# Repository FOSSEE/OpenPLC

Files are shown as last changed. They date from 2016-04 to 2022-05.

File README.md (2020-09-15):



# Introduction

- [Introduction](#introduction)
  - [What is OpenPLC?](#what-is-openplc)
  - [Our story](#our-story)
  - [Our solutions](#our-solutions)
    - [Hardware](#hardware)
    - [Software](#software)
- [Community and contributing](#community-and-contributing)
  - [Forking and cloning](#forking-and-cloning)
- [Directory Structure](#directory-structure)
- [Licence](#licence)

## What is OpenPLC?

OpenPLC is an open source **P**rogrammable **L**ogic **C**ontroller(**PLC**). Our hardware/s are functionally PLCs that can be programmed using [Ladder Logic diagram (LD)](https://en.wikipedia.org/wiki/Ladder_logic), as well as [Function Block diagram (FBD)](https://en.wikipedia.org/wiki/Function_block_diagram). We have designed the systems for academic purpose and to enable effective learning of programming PLCs. For this reason, we are also providing a set of *modules* that supplement the PLCs, which can be used to perform experiments like *simple traffic light, elevator, conveyor belt etc.*

## Our story

Few years ago we came across the need for an affordable and functional PLC for educational purposes. Every year, a large number of students in our colleges are undergoing training in PLCs without proper hands-on experience. The sky-high cost of the setup is a reason, also is the high maintenance because of being used by students. Vendor specific tools and work-flow, which are often complex, is another hindrance.

## Our solutions

### Hardware

OpenPLC consists of **two** versions
- OpenPLC Version 1 : Hardware based on AVR's [**ATmega16A**](https://www.microchip.com/wwwproducts/en/ATmega16A) and programmed using **LD**
- OpenPLC Version 2 : Hardware based on [**Raspberry Pi**](https://www.raspberrypi.org/products/raspberry-pi-zero-w/) and programmed using **FBD**

As mentioned earlier, we are also providing a set of plug-and-play modules for practising a range of experiments. The current ones are
- Elevator/Conveyor belt : Consists of a timing bet, a motor and a motor driver that can be controlled.
- Temperature Sensing and control.
- Switches : an array of *normally-open, normally-closed and latch* switches.
- Simple traffic light.

### Software

The two versions of PLCs uses two different software for programming.

- [LDMicro](Software/OpenPLCV1_LDMicro/) : A simple and intuitive LD programming IDE, used for programming *OpenPLC Version 1*. It is a forked and locally maintained version of [Jonathan Westhues](https://github.com/LDmicro/LDmicro) software.
- [4diac](https://www.eclipse.org/4diac/index.php) : A system, used for *OpenPLC version 2*, that consists of an IDE and a runtime environment for FBD programming and deployment. At present we directly use the [Eclipse 4diac](https://www.eclipse.org/4diac/) project with the Raspberry Pi work-flow.
 
*Note : Detailed documentation regarding each of the above are present in the respective directories.*

___

# Community and contributing

OpenPLC is developed by [FOSSEE](https://fossee.in/) and by users like you. We welcome both pull requests and issues on GitHub. How to and guides pertaining to both *software* and *hardware* can be found in the respective directories.

## Forking and cloning

The repository consists of a few [git submodules](https://git-scm.com/book/en/v2/Git-Tools-Submodules). To clone them along with this repo use the following command.

`git clone --recurse-submodules -j8 https://github.com/FOSSEE/OpenPLC.git'

___

# Directory Structure
      .
      ├── OpenPLC_modules     # OpenPLC modules resources including designs
      ├── OpenPLC_version_1   # OpenPLC version 1 resources including designs
      ├── OpenPLC_version_2   # OpenPLC version 2 resources including designs
      ├── LICENSE             # license
      └── README.md           # this readme

<!-- A Programmable Logic Controller generally has a set of input and output ports to which the external peripherals are connected, which are
to be electrically controlled by the PLC.
Looking into the flow of working with the PLC, the processor tries to make decisions in accordance with the program, generally written by the user using some programming language is used to write the logic and program these units.
Some of the languages commonly used are Function Block Diagram, Ladder Diagram, Structured Text, Sequential Function Chart and Instruction List.

The objective is to create an Open Source PLC, which has the capabilities of an industrial PLC, but at a much affordable and simpler user interface. Currently we have 2 versions

1. Version 1 - It incorporates a development board, that works on AVR’s ATmega16A IC, giving up to 40 pins, most of which can be used and programmed as the Input-Output pins as it’s done on a PLC.
Here the Programming language used here is Ladder Logic which is one of the easiest and also, robust in terms of its efficiency.
The main point here is, this device is a standalone device, which can work without the host system being there, just being powered by a source.
HEX files to be generated according to the controller are generated by a software called __LDMicro__, freely available for Windows and Linux users alike.
The programming on the board is done via an *USB-ASP* device through ISP headers.
All the processor wants now is a code to be dumped on it to start automating your small needs.

2. Version 2 - It uses Function Block(FB) programming language to write the logic. The system is build around a Raspberry Pi Zero, which runs a realtime environment build for IEC61499 standard. The platform we are using is **4diac**, which is implementation of IEC 16499. It has got 2 components :
   * 4diac IDE - the programming interface for writing logics using FBs.
   * FORTE - the runtime present in the actual hardware-- here a Raspberry Pi.

### The Modules

We have developed 4 different modules that goes along with the PLCs for performing experiments; trying various control methods.
   * Motor module - for controlling a motor
   * Temperature Sensing and control
   * Switches - array of various types of switches
   * Traffic light. -->

The OpenPLC setup is shown below:

<!-- ![OpenPLC Version 1(early prototype)](/Images/openplc.png "OpenPLC Version 1") -->

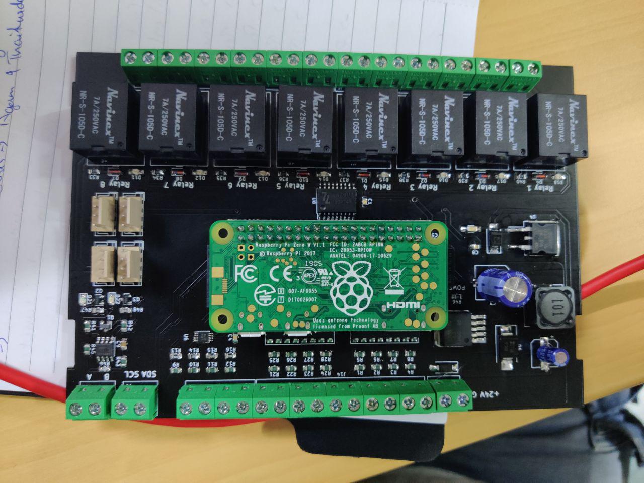
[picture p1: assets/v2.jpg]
OpenPLC Version 2


___

# Licence

OpenPLC is released under the MIT license. Some part of the software are released under other licences specified.

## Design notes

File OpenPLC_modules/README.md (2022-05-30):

# OpenPLC Modules

Addon modules for OpenPLC experiments.
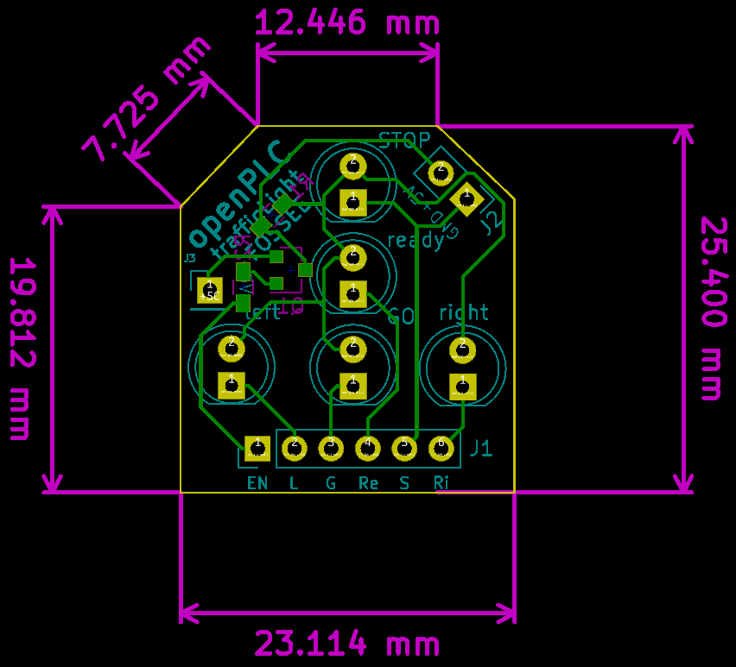
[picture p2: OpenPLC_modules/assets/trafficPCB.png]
traffic
- Traffic light - represent a 3 way traffic light 
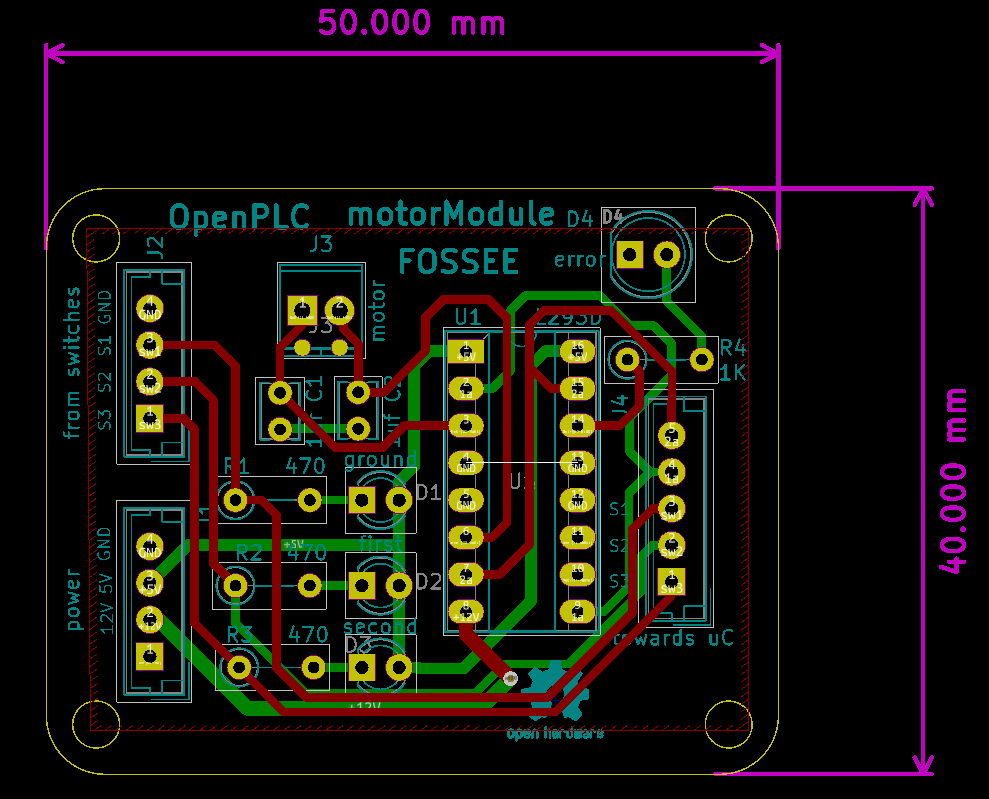
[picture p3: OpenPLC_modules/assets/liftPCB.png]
lift
- Motor driver for lift - circuit required for driving the motor, receiving and passing on the limit-switch state and as an indicator showing the given logic 
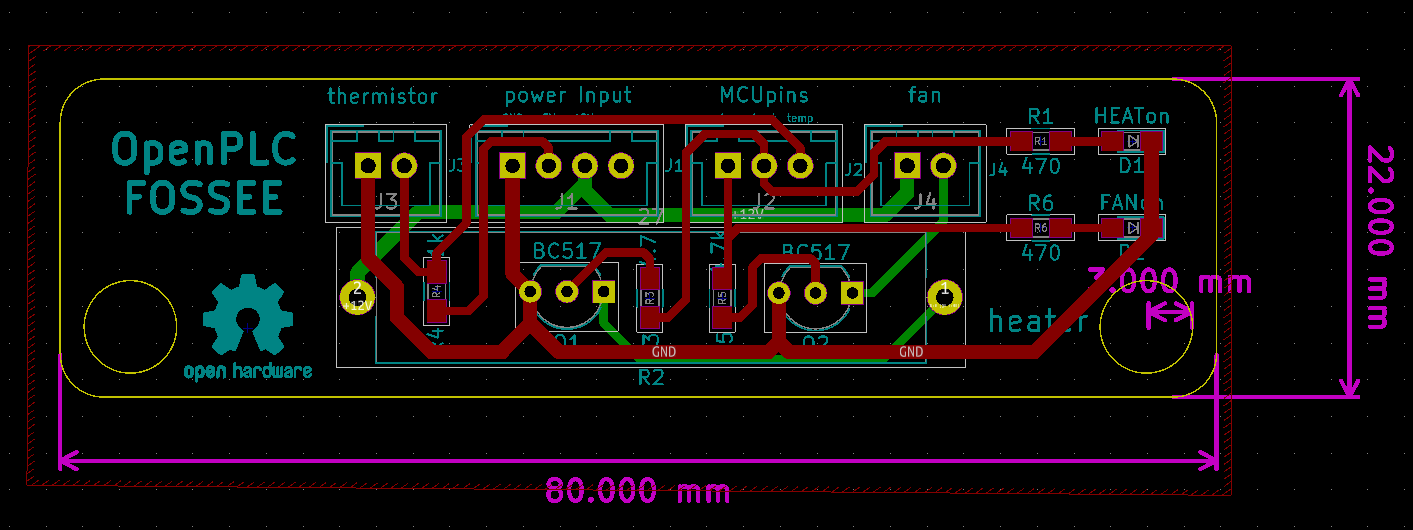
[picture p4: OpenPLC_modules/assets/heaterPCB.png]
heater
- Heater/temperature control - elements to drive the roister, which also doubles as the heating element, the cooling fan and collecting and passing on thermistor values 
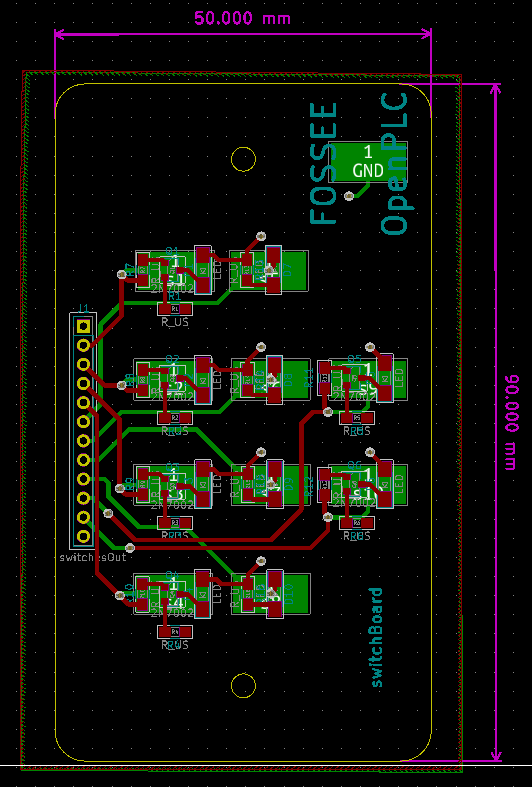
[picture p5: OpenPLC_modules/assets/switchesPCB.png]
switches
- Switches - an array of a combination of NO, NC and latch switches with indicator LEDs

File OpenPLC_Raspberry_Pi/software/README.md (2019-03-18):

# OpenPLC Version 2

Version 2 hardware is built around a Raspberry Pi. [4diac](https://www.eclipse.org/4diac/) is the associated software and you may download it from here - [Link](https://www.eclipse.org/4diac/en_dow.php).

Unlike *Version 1*, 4daic follows the [IEC 61499](https://en.wikipedia.org/wiki/IEC_61499) standard whereas the former follows **ladder logic** as defined in [IEC 6113-3](https://en.wikipedia.org/wiki/IEC_61131-3). Programs in *4daic* are written using **Function Blocks**, which are event driven sub-programs with robust data encapsulation.

## 4diac

**4daic** has got two primary components

- **4diac IDE** - It is an integrated development environment written in Java, based on the Eclipse framework. It provides an extensible engineering environment for modeling distributed control applications compliant to the IEC 61499 standard. You use 4diac IDE to create FBs, applications, configure the devices and other tasks related to IEC 61499. Within 4diac IDE, these results can also be deployed to devices running 4diac FORTE or other compliant run-time environments.

- **FORTE** - It is a small portable C++ implementation of an IEC 61499 runtime environment which supports executing IEC 61499 FB networks on small embedded devices. 4diac FORTE typically runs on top of a (real-time) OS. 4diac FORTE is a multi-threaded and low memory-consuming runtime environment. It has been tested on several different operating systems, for example, Windows, Linux (i386, amd64, ppc, xScale, arm), NetOS, eCos, rcX from Hilscher, vxWorks, and freeRTOS.

*Note: We are working on developing an exclusive forte version for our hardware and it is a work in progress. Till updated here, please choose the hardware as Raspberry Pi.*

### Learning 4diac

The official [documentation](https://www.eclipse.org/4diac/en_help.php) is the best source for learning the software a-z. You can join the [forum](https://www.eclipse.org/forums/index.php?t=thread&frm_id=308) and get support from the community too. Also, you can contact us in [***contact-openplc[at]fosse[dot]in***]().

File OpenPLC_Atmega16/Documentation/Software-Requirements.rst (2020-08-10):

Software Requirements
=====================

Many software support PLC simulation in various logic.
The software that has been used in the subsequent sections is
LDMicro, that incorporates Ladder Logic, supporting
many microcontrollers, along with the AVR's ATmega16A. This
software helps produce the HEX files according to the microcontroller
and the pin selected which can be directly dumped onto the
core.

For windows based system
------------------------

The IC is a standalone one without the Bootloader. One of the ways of
dumping the code, is using an In System Programmer or an ISP. So, for burning the same we use the software: AVRDUDE1 - AVR Downloader Uploader is a program for downloading and uploading the on-chip memories of Atmels AVR microcontrollers. It can program the Flash and EEPROM, and where supported by the serial programming protocol, it can program fuse and lock bits. It’s available as WINAVR for Windows and can be downloaded from 'here <https://sourceforge.net/projects/winavr/files/WinAVR/20100110>'_.

Setting up WINAVR
~~~~~~~~~~~~~~~~~

Step 1: First, open up the start screen and then search : Command Prompt

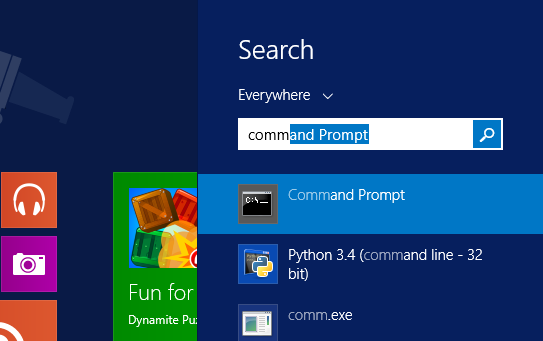
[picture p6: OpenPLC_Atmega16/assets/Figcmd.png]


Step 2: Then, a screen like this shall pop up.

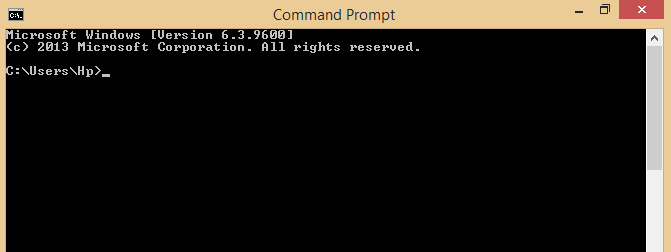
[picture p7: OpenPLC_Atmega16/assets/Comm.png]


Step 3: Enter into the command prompt for windows: avrdude

You should get prompts and flags mentioned like this, which implies that you have downloaded the software properly.

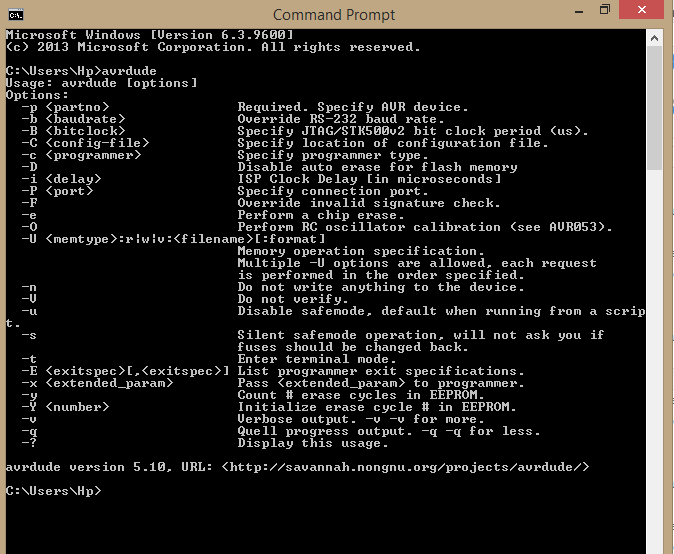
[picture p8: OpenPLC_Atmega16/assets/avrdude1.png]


For Ubuntu system
~~~~~~~~~~~~~~~~~~~~~~

Instead if you have Ubuntu system, it’s already pre-installed under the
name AVRDUDE. Just enter the below command line on your terminal

**man avrdude**

You would see a screen full of text, something like the one below. To
exit press q. If you don’t get a screen like that, then open Ubuntu Software Center and on the search bar enter avrdude, then install it. Enter the same command into the terminal again and you shall see the manual.

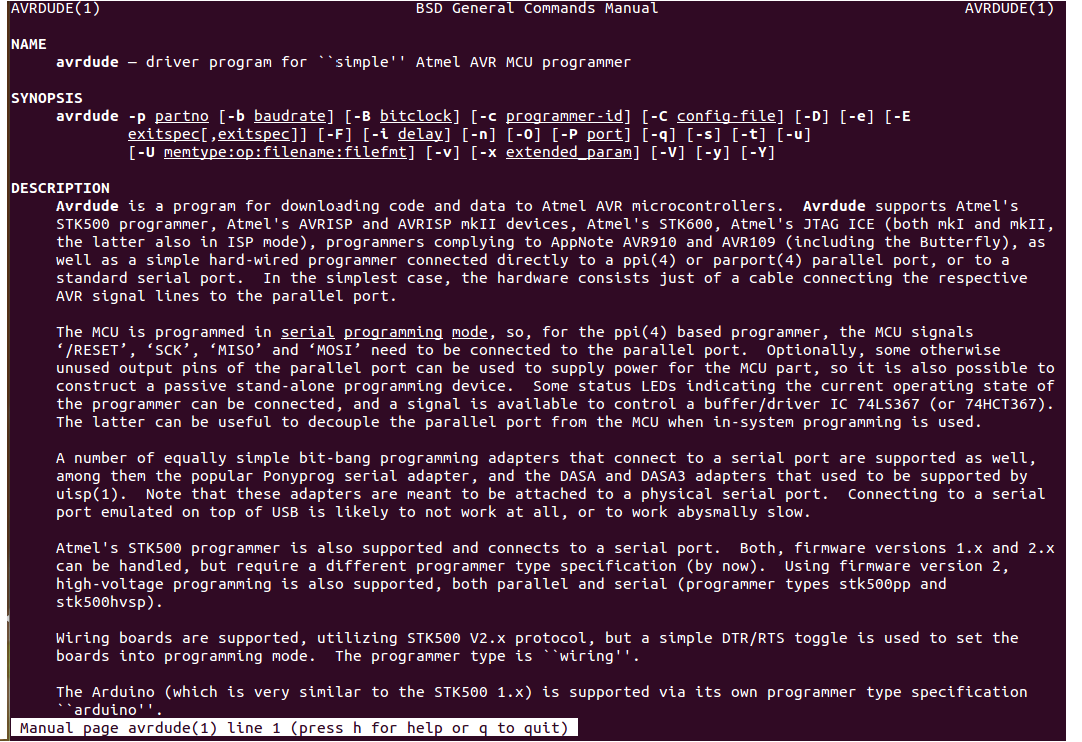
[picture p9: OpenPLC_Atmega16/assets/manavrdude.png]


Setting up the Ld micro executable
----------------------------------

To download the software on your Windows system, go to [#] `<http://cq.cx/ladder.pl/>`_ The download is a direct executable, there’s no need to install it.

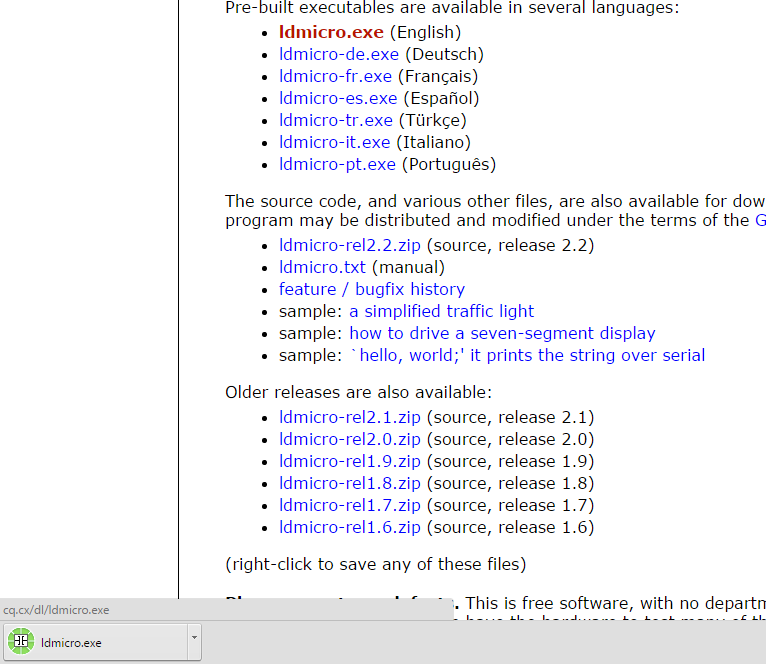
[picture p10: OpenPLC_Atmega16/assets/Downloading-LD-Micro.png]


Getting started with Ld micro
-----------------------------

A PLC is largely programmed using Ladder Logic, which is used in
this software. It allows us to select the microcontroller that 
we wish to program via its HEX codes generated, ATmega16A in this case. The naming convention is very intuitive and is easy to get accustomed to. Some of the naming conventions followed are: 

[1] *Yvar* implies the component is connected to an input pin on the micro-controller, something like a push button that is user dependent. This generally works for the digital inputs, HIGH(+5V) or LOW(GND).

[2] *Xvar* implies the component is connected to an output pin on the microcontroller. This can be something like an LED or a Buzzer that is used to show the outputs. It’s generally used to display digital outputs, HIGH(+5V) or LOW(GND).

[3] *Tvar* implies, a timer. It can be a turn on, turn off or a retentive timer, just like the ones used in the actual PLCs.

[4] *Cvar* implies a counter. The arguments in this are simple logical
operands to decide the upper bound up to which the counter shall work.
There are circular counter too, which count circularly, without any
bound.

[5] *Avar* implies the values read from the Analog pins of the controller.This can be used to take the intermediate readings say from components like Potentiometers, IR sensors etc.

Things to remember are:

- Variable names can incorporate alphabets, numbers and underscores.
  It doesn’t support the special characters.
- Do not start the name of the variable with a number.
- The variable names are case sensitive, the variable names Relay1 and
  relay1 signify two different variables.
- The instructions such as the arithmetic ones can manipulate the vari-
  ables associated with the timers, counters or input, output pins.
- The variables are 16 bit signed decimals, so the variables can also
  be containing values that are negative pertaining to that range.  
- As counters, timers in physical sense are internal in the microcontroller, we can only assign the pins to the Xname, Yname and Aname objects and not others.

Now that the basic ideas are clear, the use of certain instructions can be discussed.

We shall understand normally open and normally closed connections. In
normally open case, the contacts are open generally, which means, giving a high input closes the contact, hereby passing the signal over the rung.Whereas, a normally closed connection would imply a high signal to the connection would break the circuit hence giving low as the output.

[1] **Contacts** are something like a prototype of a switch, which implies, if the signal going into the contact is true, only then it’ll be reflected as output, if false, then output is false for normally open case. These can be used as internal relays too.

[2] **Coils** are basically corresponding to the output devices. They can set the output true, if the signal going into them is true for the normally open case, else it’s the other way. They can be used with internal relays too. There is an option of Set only (Reset-only) which are set(reset) when the input goes from Low to High, and retain their states. Hence they are used with Reset-Only(Set-Only) coils to change the states as and when wanted.

[3] **Internal Relays** are the ones that are never assigned pin numbers.Basically, they are the ones that are used for counters or triggers, which are not given inputs or outputs, hence no pin on the controller.

[4] **Turn on Delay** simply means delaying turning on of any coil. This mean the sensor, if gives a high at the input, it delays the turning on of the next part of the rung by those many units of time

[5] **Turn off Delay** literally means turning off of any coil with some delay.This mean the sensor, if gives a false or a low at the input, it delays the turning off of the next part of the rung by those many units of time

[6] **Retentive timer** is used to keep track of the how much time the
module under consideration has been true, it cumulates the total time,
if the input has been on for at-least that much time, the output of the
timer is true. It will always remain true after this, hence it should be reset by using Reset instruction manually

[7] **Counter** is used to count up to the given value threshold.The count is changed as the input to the counter is made high. This is used as an up counter, down counter or a circular counter. The variables can be manipulated and be suited for the application

[8] **Mov** is used to move any value, be it character or numeric into the variable named under destination.

[9] **Arithmetic operands** are used to manipulate the variables values to suit the logic, they can be used on any kind of variables like the counters variables.

These are the basic ones that are used. A detailed help for the more
instructions and general guidelines is provided on the Manual of the
software under the Help menu.

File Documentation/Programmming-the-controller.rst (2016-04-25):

Programming the Controller
==========================

There are several programmers available to program any controller IC. They are called as ISPs. USBASP is one of them. Before programming the IC, we need to set the fuses. 

Setting up fuse bits
--------------------

Now that the programmer is installed on the system, we need to adjust the
properties of the controller IC such that it meets the necessary requirements along with the peripherals installed on the board. Essentially, fuse bits are the ones that decide how the controller responds, like which clock frequency it responds to or its programming availabilities.

Setting up the fuse is a crucial task as the controller may not respond later if the fuse bits that are set are not in accordance with the attached peripherals. Before setting the fuses, the factory settings on the controller make sure it works on the internal oscillator of clock speed 1MHz. It’s mostly dependent on 2 fuses - lfuse and hfuse. Both of these have hex 8 bit values. When working on communication with the device, like UART, these fuse bits play a key role, if not defined, the
controller works on the internal clock that’s much slower than the externalcrystal. For the controller, 16MHz external crystal was selected. This meant the controller shall configure this external crystal and work on it.

**WARNING:** Fuse bits control the way the controller responds. If
any mistake is made in setting up the fuse bits, then the controller
becomes isolated from the external circuit. This means that the
controller doesn’t respond and renders useless. Hence, always triple
check before entering the fuse bits. This is the best practice,
or else you may end up wasting one IC.

Type the following command into the Terminal:

**sudo avrdude -p m16 -c usbasp -U lfuse:w:0xFF:m -U hfuse:w:0xD9:m -B10**

Screen like below will pop up after giving the command line

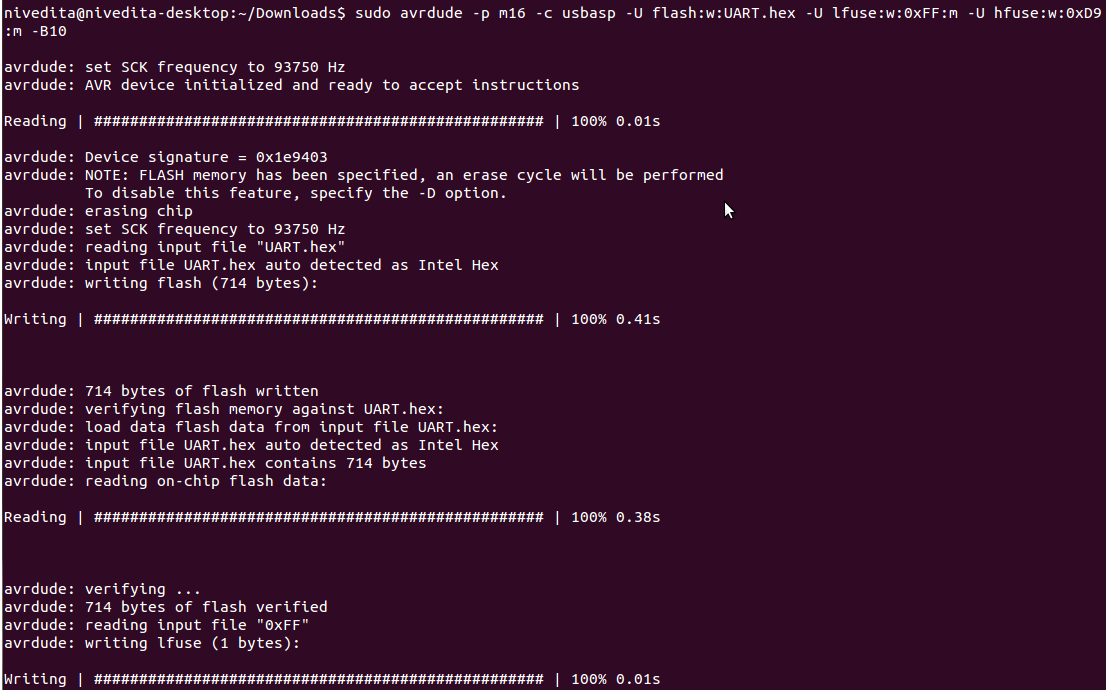
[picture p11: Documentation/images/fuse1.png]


You can read fust bits after setting up, as shown below, 

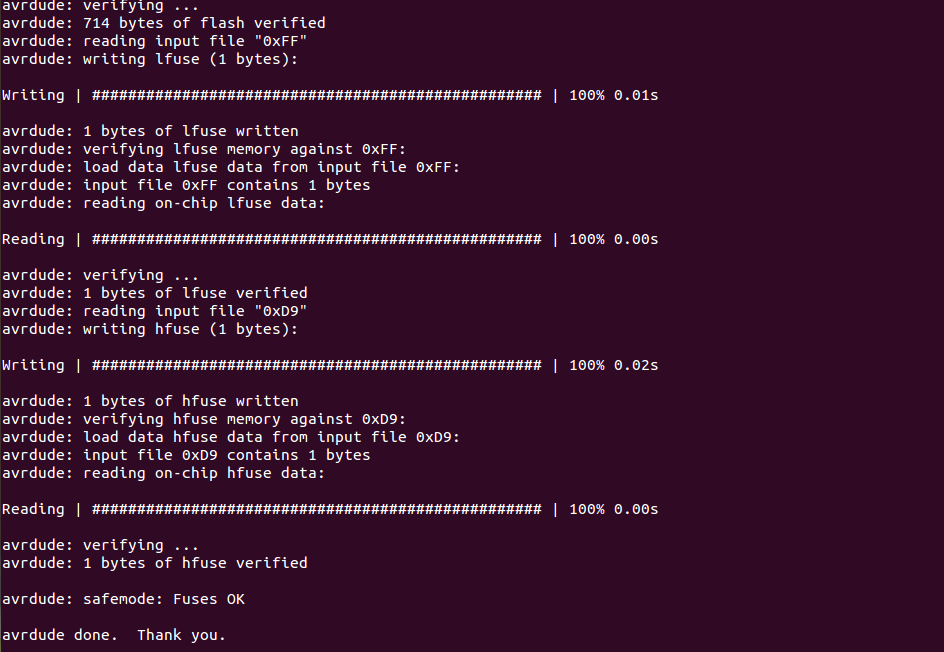
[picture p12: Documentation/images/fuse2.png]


Now the external crystal is working in sync with the controller. 

USBASP as ISP
-------------

Step 1: We require a precompiled hex file to be burnt onto our microcontroller. In our case, we have generated it by doing simple ladder programming in LDMicro and then compiling it. Before that, ensure that the proper target controller from the drop-down menu is chosen. For input and output part, assign a certain pin no. of the controller to that of the desired application. Now, a certain name is given to the file(say, blink.hex) at the destination folder.

Step 2: After being done with all the software part, one shall supply the power from 12V SMPS to the development board. Now check whether the
controller is powered up properly with 5 Volt or not from the appropriate Vcc and GND pins of the controller.

Step 3: Now, just connect the FRC cable from USBASP to the 10 pin
shrouded header on the board.

Step 4: Now, turn on Terminal and then change the directory to the one
in which you have the saved HEX file to be dumped onto the processor.

Step 5: Now, in the terminal, enter the following command.

**sudo avrdude -p atmega16 -P usb -c usbasp -B10 -U flash:w:Blink.hex**

You shall see such a process going on in the terminal like the one shown
below, which means that the process of erasing and writing the internal
memory of the ATmega IC is in the process. On correct execution you shall
get such a result. Whilst it’s burning the code, the red light on the USBASP will be lit showing that it is communicating with the controller appropriately.

Remember, after the fuses are set (covered in the following sections in
detail), then the -B10 flag is necessary and can be deleted.

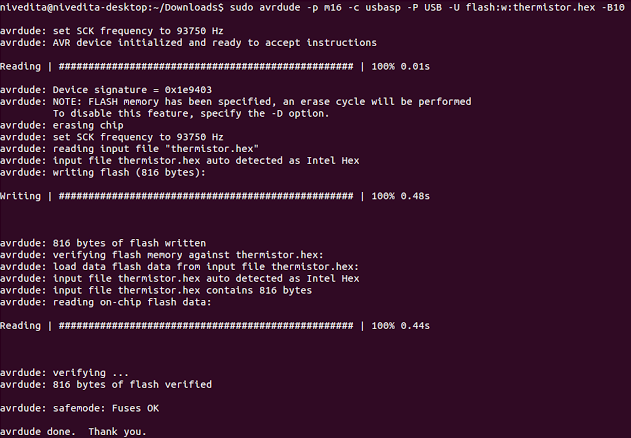
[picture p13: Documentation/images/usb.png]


Trouble shooting
~~~~~~~~~~~~~~~~

- Check if the board is powered from the SMPS, if not, power it and try
  it once powered.
- Check if all the essential flags in the command line are incorporated, 
  if not make the appropriate changes.
- Check if the FRC cable of the USBASP is not stranded in the midway,
  if so, replace it.
- If all these fail, check if the appropriate MOSI, MISO, SCK, RST and
  GND pins of the header are appropriately shorted with the ones of the  
  IC and also that the controller firmly sits on the base.

These are the main errors you may get while programming the PLC.

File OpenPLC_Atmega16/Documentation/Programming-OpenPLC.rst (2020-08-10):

Programming the OpenPLC Board
==========================

There are several programmers available to program any controller IC. They are called as ISPs. USBASP is one of them. Before programming the IC, we need to set the fuses. 

Setting up fuse bits
--------------------

Now that the programmer is installed on the system, we need to adjust the
properties of the controller IC such that it meets the necessary requirements along with the peripherals installed on the board. Essentially, fuse bits are the ones that decide how the controller responds, like which clock frequency it responds to or its programming availabilities.

Setting up the fuse is a crucial task as the controller may not respond later if the fuse bits that are set are not in accordance with the attached peripherals. Before setting the fuses, the factory settings on the controller make sure it works on the internal oscillator of clock speed 1MHz. It’s mostly dependent on 2 fuses - lfuse and hfuse. Both of these have hex 8 bit values. When working on communication with the device, like UART, these fuse bits play a key role, if not defined, the
controller works on the internal clock that’s much slower than the external crystal. For the controller, 16MHz external crystal was selected. This meant the controller shall configure this external crystal and work on it.

**WARNING:** Fuse bits control the way the controller responds. If
any mistake is made in setting up the fuse bits, then the controller
becomes isolated from the external circuit. This means that the
controller doesn’t respond and renders useless. Hence, always triple
check before entering the fuse bits. This is the best practice,
or else you may end up wasting one IC.

Type the following command into the Terminal:

**sudo avrdude -p m16 -c usbasp -U lfuse:w:0xFF:m -U hfuse:w:0xD9:m -B10**

Screen like below will pop up after giving the command line



You can read fuse bits after setting up, as shown below, 



Now the external crystal is working in sync with the controller. 

USBASP as ISP
-------------

Step 1: We require a pre-compiled hex file to be burnt onto our microcontroller. In our case, we have generated it by doing simple ladder programming in LDMicro and then compiling it. Before that, ensure that the proper target controller from the drop-down menu is chosen. For input and output part, assign a certain pin no. of the controller to that of the desired application. Now, a certain name is given to the file(say, blink.hex) at the destination folder.

Step 2: After being done with all the software part, one shall supply the power from 12V SMPS to the development board. Now check whether the
controller is powered up properly with 5 Volt or not from the appropriate Vcc and GND pins of the controller.

Step 3: Now, just connect the FRC cable from USBASP to the 10 pin
shrouded header on the board.

Step 4: Now, turn on Terminal and then change the directory to the one
in which you have the saved HEX file to be dumped onto the processor.

Step 5: Now, in the terminal, enter the following command.

**sudo avrdude -c usbasp -p m16-U flash:w:Blink.hex**

You shall see such a process going on in the terminal like the one shown
below, which means that the process of erasing and writing the internal
memory of the ATmega IC is in the process. On correct execution you shall
get such a result. Whilst it’s burning the code, the red light on the USBASP will be lit showing that it is communicating with the controller appropriately.

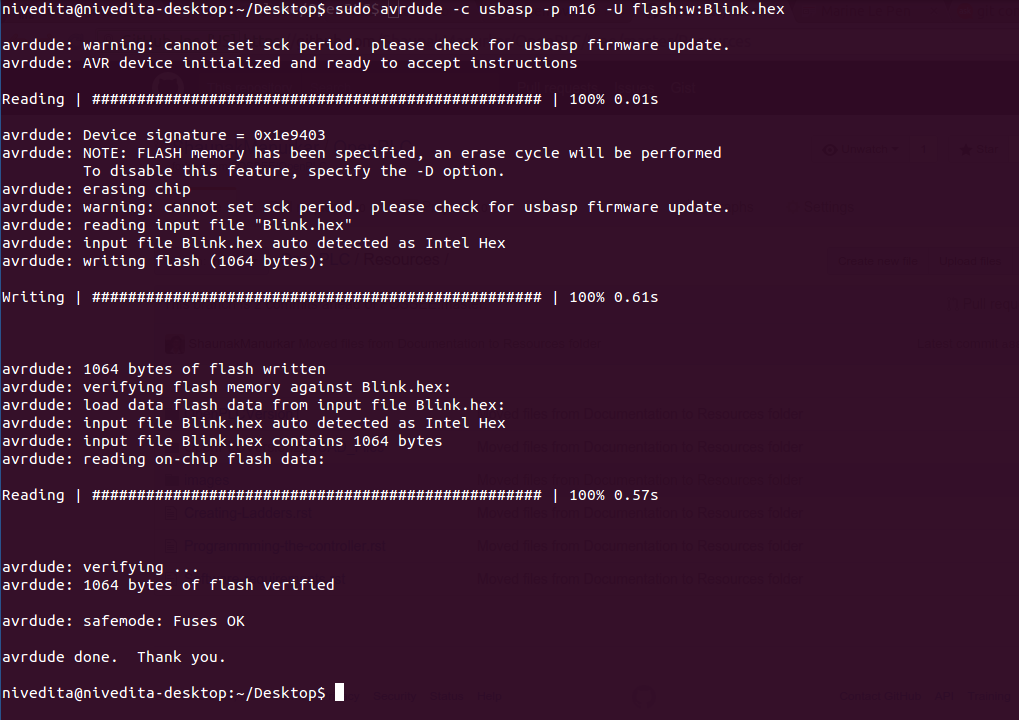
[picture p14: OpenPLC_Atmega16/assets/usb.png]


Trouble shooting
~~~~~~~~~~~~~~~~

- Check if the board is powered from the SMPS, if not, power it and try
  it once powered.
- Check if all the essential flags in the command line are incorporated, 
  if not make the appropriate changes.
- Check if the FRC cable of the USBASP is not stranded in the midway,
  if so, replace it.
- If all these fail, check if the appropriate MOSI, MISO, SCK, RST and
  GND pins of the header are appropriately shorted with the ones of the  
  IC and also that the controller firmly sits on the base.

These are the main errors you may get while programming the PLC.

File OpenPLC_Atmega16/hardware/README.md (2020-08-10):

# Version

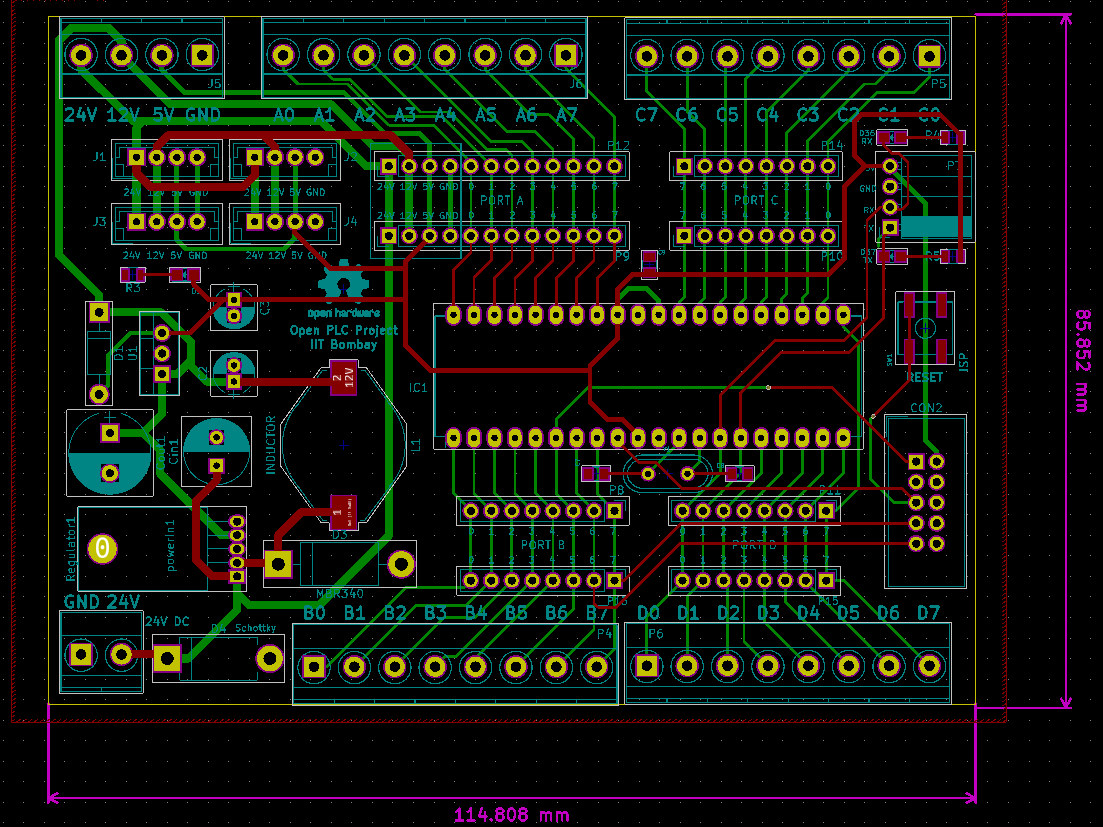
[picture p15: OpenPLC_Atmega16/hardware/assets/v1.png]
Version 1.2


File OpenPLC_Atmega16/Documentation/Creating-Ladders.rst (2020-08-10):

Creating Ladders using Ld micro
===============================

LD Micro’s simple user interface is really easy to use and is self explanatory.To get started working with LD Micro, just double click the LD Micro executable present in your system. Once opened, you shall get such a GUI.

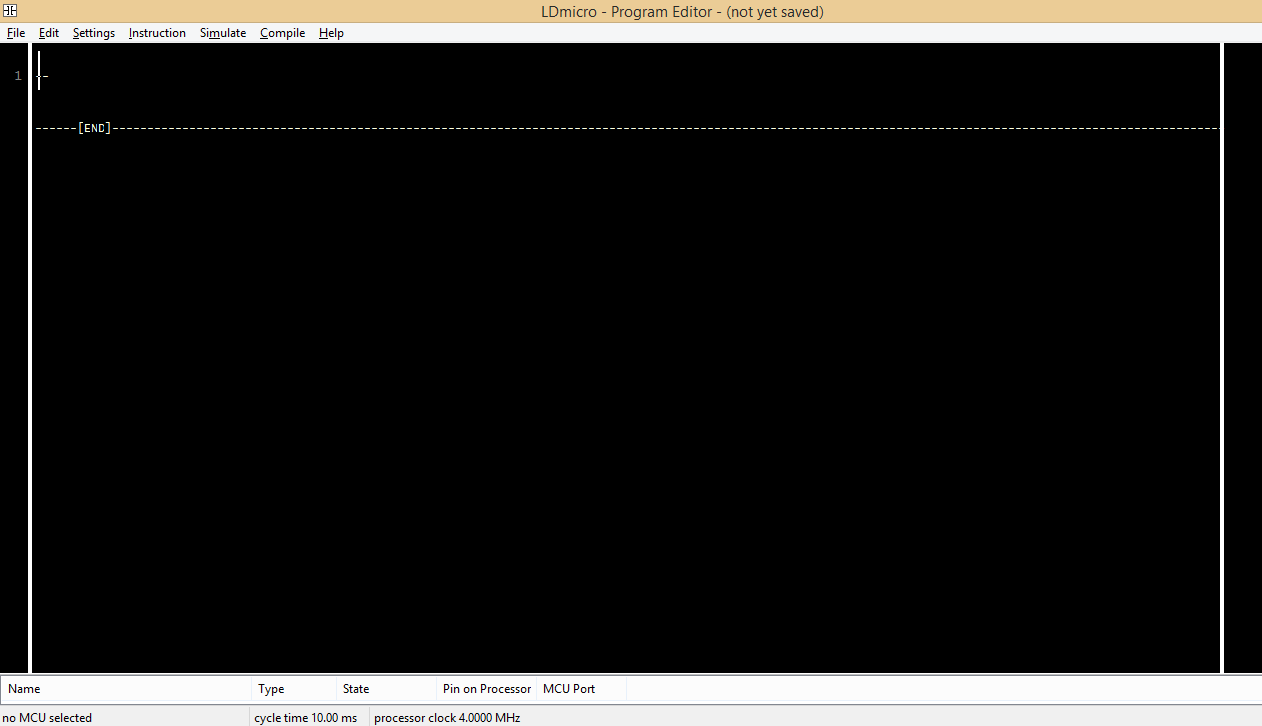
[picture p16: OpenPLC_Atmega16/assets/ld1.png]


Before starting to make the ladder, first make the necessary changes in
the default settings, so as to generate the HEX code for your microcontroller.

Under Settings tab, select the MCU Parameters Option

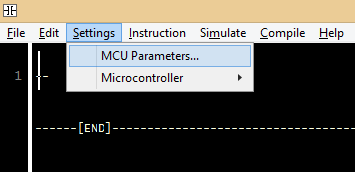
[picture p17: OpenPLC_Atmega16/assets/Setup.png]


Then after selecting, change the clock frequency to 16MHz and if using
UART change the baud rate to 9600.

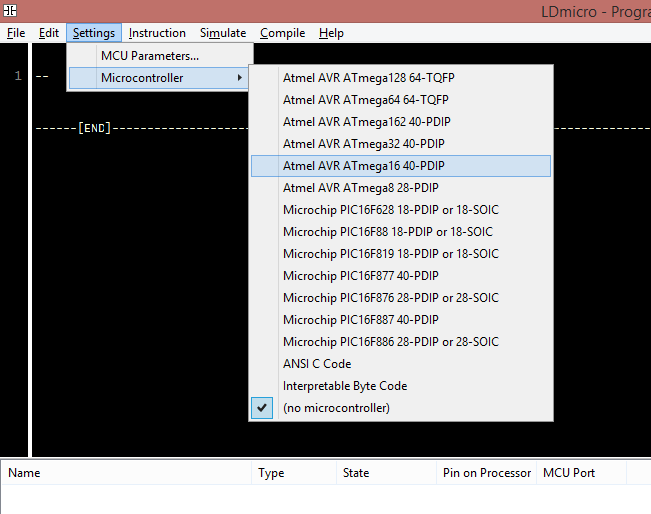
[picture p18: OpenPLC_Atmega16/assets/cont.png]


Now that the configurations are set, the next step can be followed to
design the ladder with the appropriate logic.

Start off with having a look at the Instruction tab. It has a lot of
instructions that are in accordance with the Ladder logic followed for the PLCs and work in the same way and are similar to the ones described above under the ’Understanding the Instructions’ section.

After selecting the appropriate instruction, just double click the instruction to edit the name of the variable and other parameters related to the particular instruction.

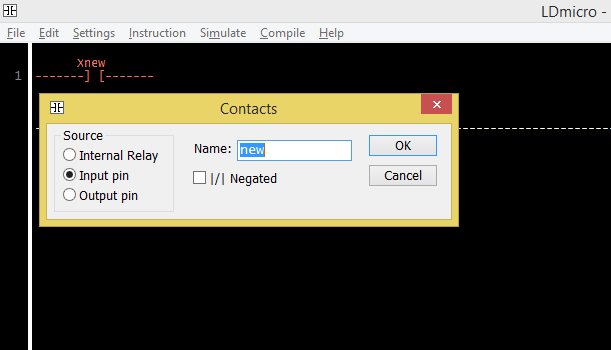
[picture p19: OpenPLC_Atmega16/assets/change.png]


After making the appropriate ladder for the application, the digital input and outputs should be given an appropriate pin number of the controller and the connections should be done accordingly. This can be done by double clicking the appropriate pin to be configured in the consolidated table just below the ladder made.

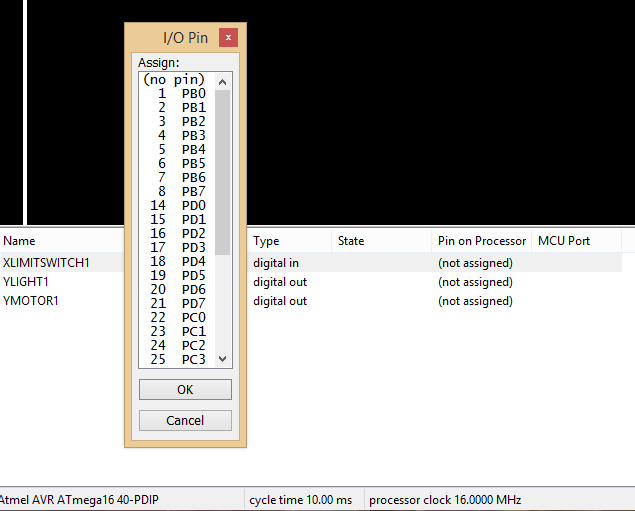
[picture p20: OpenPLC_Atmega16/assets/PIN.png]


Now that the logic is set, the ladder can be simulated to verify it’s working. This is done by clicking the Simulate tab and Simulation Mode option under it. This is then followed by a similar screen where Blue indicates LOW and Pink indicates HIGH. To start the simulation, under Simulate tab click Start Real-Time Simulation option. After this, to change the state, just double click the instruction. The appropriate changes and values pertaining to different variables can be seen in the consolidated instruction table under the State column. To come out of simulation mode, click the same Simulation Mode option.

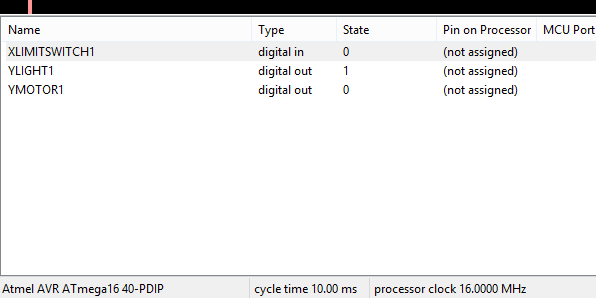
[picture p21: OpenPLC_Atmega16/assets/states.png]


After the ladder along with assigning the appropriate pin numbers, the
HEX code can be generated. This can be done by first saving the ladder
under the File tab with the Save As option. Save the file in the appropriate destination folder with a suitable name. Remember the final destination of the same for future. Now, to generate the HEX file, select the Compile tab and then the option Compile As. Then save this text file in the desired destination folder. The location shall be noted as it’d be needed to burn the code onto the controller using the command line arguments later.

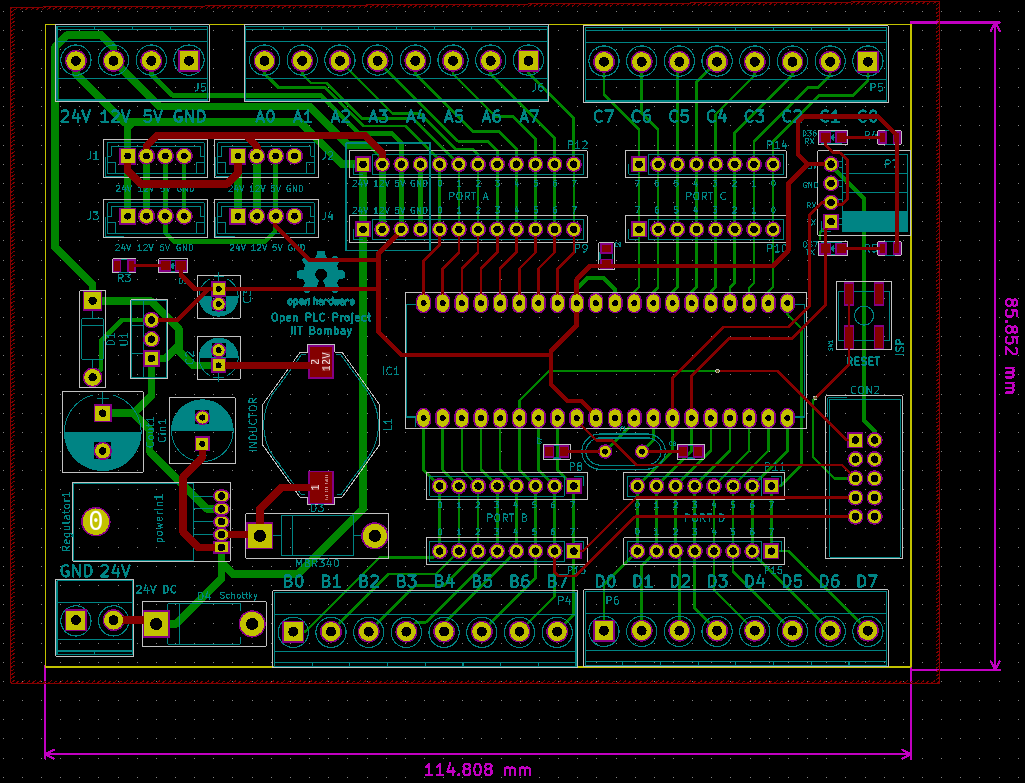
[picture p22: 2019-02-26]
OpenPLC_modules/assets/v1.png

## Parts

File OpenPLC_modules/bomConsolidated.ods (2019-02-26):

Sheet: v1
Date: | Tue 22 Jan 2019 12:48:19 PM IST
Tool: | Eeschema 5.0.1
Component Count: | 41
Individual Components:
Item | Qty | Reference(s) | Value | LibPart | Footprint | Datasheet
 |  | C2 | 100uF | OpenPLC_V2-rescue:CP | Capacitors_THT:CP_Radial_D5.0mm_P2.00mm
 |  | C3 | 10uF | OpenPLC_V2-rescue:CP | Capacitors_THT:CP_Radial_D5.0mm_P2.00mm
 |  | C7 | 22pF | OpenPLC_V2-rescue:CP1 | Capacitors_SMD:C_0805
 |  | C8 | 22pF | OpenPLC_V2-rescue:CP1 | Capacitors_SMD:C_0805
 |  | C9 | 100nF | OpenPLC_V2-rescue:C_Small | Capacitors_SMD:C_0805
 |  | CON2 | AVR-ISP-10 | OpenPLC_V2-rescue:AVR-ISP-10 | IDC:IDC-Header_2x05_Pitch2.54mm_Straight
 |  | Cin1 | 100uf | Device:CP | Capacitors_THT:CP_Radial_D8.0mm_P3.50mm
 |  | Cout1 | 1000uf | Device:CP | Capacitors_THT:CP_Radial_D10.0mm_P5.00mm
 |  | D1 | D | OpenPLC_V2-rescue:D | Diodes_THT:D_DO-41_SOD81_P10.16mm_Horizontal
 |  | D2 | LED | OpenPLC_Kicad_Single_Strip_Unordered-rescue:LED-RESCUE-OpenPLC_Kicad_Single_Strip_Unordered | LEDs:LED_0805
 |  | D3 | MBR340 | Diode:MBR340 | Diodes_THT:D_DO-201AD_P15.24mm_Horizontal | http://www.onsemi.com/pub_link/Collateral/MBR340-D.PDF
 |  | D4 | D_Schottky | OpenPLC_V2-rescue:D_Schottky-Device | Diodes_THT:D_DO-201AD_P12.70mm_Horizontal | ~
 |  | D36 | RX | OpenPLC_Kicad_Single_Strip_Unordered-rescue:LED-RESCUE-OpenPLC_Kicad_Single_Strip_Unordered | LEDs:LED_0805
 |  | D37 | TX | OpenPLC_Kicad_Single_Strip_Unordered-rescue:LED-RESCUE-OpenPLC_Kicad_Single_Strip_Unordered | LEDs:LED_0805
 |  | IC1 | ATMEGA16-P | OpenPLC_Modular-rescue:ATMEGA16-P-RESCUE-OpenPLC_Modular | Housings_DIP:DIP-40_W15.24mm_LongPads
 |  | J1 | Conn_01x04 | OpenPLC_V2-rescue:Conn_01x04 | Connectors_JST:JST_EH_B04B-EH-A_04x2.50mm_Straight
 |  | J2 | Conn_01x04 | OpenPLC_V2-rescue:Conn_01x04 | Connectors_JST:JST_EH_B04B-EH-A_04x2.50mm_Straight
 |  | J3 | Conn_01x04 | OpenPLC_V2-rescue:Conn_01x04 | Connectors_JST:JST_EH_B04B-EH-A_04x2.50mm_Straight
 |  | J4 | Conn_01x04 | OpenPLC_V2-rescue:Conn_01x04 | Connectors_JST:JST_EH_B04B-EH-A_04x2.50mm_Straight
 |  | L1 | INDUCTOR | OpenPLC_V2-rescue:INDUCTOR | Inductors_SMD:L_Fastron_PISR_Handsoldering
 |  | P3 | PortA | OpenPLC_V2-rescue:Conn_01x12 | TerminalBlocks_Phoenix:TerminalBlock_Phoenix_MKDS1.5-12pol
 |  | P4 | PortB | OpenPLC_V2-rescue:Conn_01x08 | TerminalBlocks_Phoenix:TerminalBlock_Phoenix_MKDS1.5-8pol
 |  | P5 | PortC | OpenPLC_V2-rescue:Conn_01x08 | TerminalBlocks_Phoenix:TerminalBlock_Phoenix_MKDS1.5-8pol
 |  | P6 | PortD | OpenPLC_V2-rescue:Conn_01x08 | TerminalBlocks_Phoenix:TerminalBlock_Phoenix_MKDS1.5-8pol
 |  | P7 | Max232 | OpenPLC_V2-rescue:Conn_01x04 | Socket_Strips:Socket_Strip_Angled_1x04_Pitch2.54mm
 |  | P8 | PortB_B | OpenPLC_V2-rescue:Conn_01x08 | Socket_Strips:Socket_Strip_Straight_1x08_Pitch2.54mm
 |  | P9 | PortA_B | OpenPLC_V2-rescue:Conn_01x12 | Socket_Strips:Socket_Strip_Straight_1x12_Pitch2.54mm
 |  | P10 | PortC_B | OpenPLC_V2-rescue:Conn_01x08 | Socket_Strips:Socket_Strip_Straight_1x08_Pitch2.54mm
 |  | P11 | PortD_B | OpenPLC_V2-rescue:Conn_01x08 | Socket_Strips:Socket_Strip_Straight_1x08_Pitch2.54mm
 |  | P12 | PortA_M | OpenPLC_V2-rescue:Conn_01x12 | Pin_Headers:Pin_Header_Straight_1x12_Pitch2.54mm
 |  | P13 | PortB_M | OpenPLC_V2-rescue:Conn_01x08 | Pin_Headers:Pin_Header_Straight_1x08_Pitch2.54mm
 |  | P14 | PortC_M | OpenPLC_V2-rescue:Conn_01x08 | Pin_Headers:Pin_Header_Straight_1x08_Pitch2.54mm
 |  | P15 | PortD_M | OpenPLC_V2-rescue:Conn_01x08 | Pin_Headers:Pin_Header_Straight_1x08_Pitch2.54mm
 |  | R3 | 470E | OpenPLC_V2-rescue:R | Resistors_SMD:R_0805
 |  | R4 | 1K | OpenPLC_V2-rescue:R_Small | Resistors_SMD:R_0805
 |  | R5 | 1K | OpenPLC_V2-rescue:R_Small | Resistors_SMD:R_0805
 |  | Regulator1 | 24 to 12 | Regulator_Switching:LM2576HVT-12 | TO_SOT_Packages_THT:TO-220-5_Horizontal | http://www.ti.com/lit/ds/symlink/lm2576.pdf
 |  | SW1 | SW_PUSH | OpenPLC_V2-rescue:SW_PUSH | Buttons_Switches_SMD:SW_SPST_B3SL-1002P
 |  | U1 | 7805 | OpenPLC_Kicad_Single_Strip_Unordered-rescue:7805-RESCUE-OpenPLC_Kicad_Single_Strip_Unordered | TO_SOT_Packages_THT:TO-220-3_Vertical
 |  | Y1 | 16Mhz | OpenPLC_V2-rescue:Crystal | Crystals:Crystal_HC49-U_Vertical
 |  | powerIn1 | 24V | OpenPLC_V2-rescue:Screw_Terminal_01x02-Connector | TerminalBlocks_Phoenix:TerminalBlock_Phoenix_MKDS1.5-2pol | ~
Collated Components:
Item | Qty | Reference(s) | Value | LibPart | Footprint | Datasheet
1 | 1 | C2 | 100uF | OpenPLC_V2-rescue:CP | Capacitors_THT:CP_Radial_D5.0mm_P2.00mm
2 | 1 | C3 | 10uF | OpenPLC_V2-rescue:CP | Capacitors_THT:CP_Radial_D5.0mm_P2.00mm
3 | 2 | C7, C8 | 22pF | OpenPLC_V2-rescue:CP1 | Capacitors_SMD:C_0805
4 | 1 | C9 | 100nF | OpenPLC_V2-rescue:C_Small | Capacitors_SMD:C_0805
5 | 1 | CON2 | AVR-ISP-10 | OpenPLC_V2-rescue:AVR-ISP-10 | IDC:IDC-Header_2x05_Pitch2.54mm_Straight
6 | 1 | Cin1 | 100uf | Device:CP | Capacitors_THT:CP_Radial_D8.0mm_P3.50mm
7 | 1 | Cout1 | 1000uf | Device:CP | Capacitors_THT:CP_Radial_D10.0mm_P5.00mm
8 | 1 | D1 | D | OpenPLC_V2-rescue:D | Diodes_THT:D_DO-41_SOD81_P10.16mm_Horizontal
9 | 1 | D2 | LED | OpenPLC_Kicad_Single_Strip_Unordered-rescue:LED-RESCUE-OpenPLC_Kicad_Single_Strip_Unordered | LEDs:LED_0805
10 | 1 | D3 | MBR340 | Diode:MBR340 | Diodes_THT:D_DO-201AD_P15.24mm_Horizontal | http://www.onsemi.com/pub_link/Collateral/MBR340-D.PDF
11 | 1 | D4 | D_Schottky | OpenPLC_V2-rescue:D_Schottky-Device | Diodes_THT:D_DO-201AD_P12.70mm_Horizontal | ~
12 | 1 | D36 | RX | OpenPLC_Kicad_Single_Strip_Unordered-rescue:LED-RESCUE-OpenPLC_Kicad_Single_Strip_Unordered | LEDs:LED_0805
13 | 1 | D37 | TX | OpenPLC_Kicad_Single_Strip_Unordered-rescue:LED-RESCUE-OpenPLC_Kicad_Single_Strip_Unordered | LEDs:LED_0805
14 | 1 | IC1 | ATMEGA16-P | OpenPLC_Modular-rescue:ATMEGA16-P-RESCUE-OpenPLC_Modular | Housings_DIP:DIP-40_W15.24mm_LongPads
15 | 4 | J1, J2, J3, J4 | Conn_01x04 | OpenPLC_V2-rescue:Conn_01x04 | Connectors_JST:JST_EH_B04B-EH-A_04x2.50mm_Straight
16 | 1 | L1 | INDUCTOR | OpenPLC_V2-rescue:INDUCTOR | Inductors_SMD:L_Fastron_PISR_Handsoldering
17 | 1 | P3 | PortA | OpenPLC_V2-rescue:Conn_01x12 | TerminalBlocks_Phoenix:TerminalBlock_Phoenix_MKDS1.5-12pol
18 | 1 | P4 | PortB | OpenPLC_V2-rescue:Conn_01x08 | TerminalBlocks_Phoenix:TerminalBlock_Phoenix_MKDS1.5-8pol
19 | 1 | P5 | PortC | OpenPLC_V2-rescue:Conn_01x08 | TerminalBlocks_Phoenix:TerminalBlock_Phoenix_MKDS1.5-8pol
20 | 1 | P6 | PortD | OpenPLC_V2-rescue:Conn_01x08 | TerminalBlocks_Phoenix:TerminalBlock_Phoenix_MKDS1.5-8pol
21 | 1 | P7 | Max232 | OpenPLC_V2-rescue:Conn_01x04 | Socket_Strips:Socket_Strip_Angled_1x04_Pitch2.54mm
22 | 1 | P8 | PortB_B | OpenPLC_V2-rescue:Conn_01x08 | Socket_Strips:Socket_Strip_Straight_1x08_Pitch2.54mm
23 | 1 | P9 | PortA_B | OpenPLC_V2-rescue:Conn_01x12 | Socket_Strips:Socket_Strip_Straight_1x12_Pitch2.54mm
24 | 1 | P10 | PortC_B | OpenPLC_V2-rescue:Conn_01x08 | Socket_Strips:Socket_Strip_Straight_1x08_Pitch2.54mm
25 | 1 | P11 | PortD_B | OpenPLC_V2-rescue:Conn_01x08 | Socket_Strips:Socket_Strip_Straight_1x08_Pitch2.54mm
26 | 1 | P12 | PortA_M | OpenPLC_V2-rescue:Conn_01x12 | Pin_Headers:Pin_Header_Straight_1x12_Pitch2.54mm
27 | 1 | P13 | PortB_M | OpenPLC_V2-rescue:Conn_01x08 | Pin_Headers:Pin_Header_Straight_1x08_Pitch2.54mm
28 | 1 | P14 | PortC_M | OpenPLC_V2-rescue:Conn_01x08 | Pin_Headers:Pin_Header_Straight_1x08_Pitch2.54mm
29 | 1 | P15 | PortD_M | OpenPLC_V2-rescue:Conn_01x08 | Pin_Headers:Pin_Header_Straight_1x08_Pitch2.54mm
30 | 1 | R3 | 470E | OpenPLC_V2-rescue:R | Resistors_SMD:R_0805
31 | 2 | R4, R5 | 1K | OpenPLC_V2-rescue:R_Small | Resistors_SMD:R_0805
32 | 1 | Regulator1 | 24 to 12 | Regulator_Switching:LM2576HVT-12 | TO_SOT_Packages_THT:TO-220-5_Horizontal | http://www.ti.com/lit/ds/symlink/lm2576.pdf
33 | 1 | SW1 | SW_PUSH | OpenPLC_V2-rescue:SW_PUSH | Buttons_Switches_SMD:SW_SPST_B3SL-1002P
34 | 1 | U1 | 7805 | OpenPLC_Kicad_Single_Strip_Unordered-rescue:7805-RESCUE-OpenPLC_Kicad_Single_Strip_Unordered | TO_SOT_Packages_THT:TO-220-3_Vertical
35 | 1 | Y1 | 16Mhz | OpenPLC_V2-rescue:Crystal | Crystals:Crystal_HC49-U_Vertical
36 | 1 | powerIn1 | 24V | OpenPLC_V2-rescue:Screw_Terminal_01x02-Connector | TerminalBlocks_Phoenix:TerminalBlock_Phoenix_MKDS1.5-2pol | ~
Extras
Item | Qty | Part
1 | 1 | USB-ASP Programmer
2 | 1 | Programmer cable

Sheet: traffic
Date: | Tue 22 Jan 2019 05:36:43 PM IST
Tool: | Eeschema 5.0.1
Component Count: | 11
Individual Components:
Reference(s) | Value | LibPart | Footprint | Datasheet
D1 | left | Device:LED | LEDs:LED_D5.0mm | ~
D2 | GO | Device:LED | LEDs:LED_D5.0mm | ~
D3 | right | Device:LED | LEDs:LED_D5.0mm | ~
D4 | ready | Device:LED | LEDs:LED_D5.0mm | ~
D5 | STOP | Device:LED | LEDs:LED_D5.0mm | ~
J1 | Conn_01x06_Male | Connector:Conn_01x06_Male | Socket_Strips:Socket_Strip_Straight_1x06_Pitch2.54mm | ~
J2 | Conn_01x02_Male | Connector:Conn_01x02_Male | Socket_Strips:Socket_Strip_Straight_1x02_Pitch2.54mm | ~
J3 | Conn_01x01_Male | Connector:Conn_01x01_Male | Socket_Strips:Socket_Strip_Straight_1x01_Pitch2.54mm |  |  | ~
Q1 | MMBT3906 | Transistor_BJT:MMBT3906 | TO_SOT_Packages_SMD:SOT-23 | https://www.fairchildsemi.com/datasheets/2N/2N3906.pdf | Q1 | MMBT3906 | Transistor_BJT:MMBT3906 | TO_SOT_Packages_SMD:SOT-23 | https://www.fairchildsemi.com/datasheets/2N/2N3906.pdf | Q1 | MMBT3906 | Transistor_BJT:MMBT3906 | TO_SOT_Packages_SMD:SOT-23 | https://www.fairchildsemi.com/datasheets/2N/2N3906.pdf | Q1 | MMBT3906 | Transistor_BJT:MMBT3906 | TO_SOT_Packages_SMD:SOT-23 | https://www.fairchildsemi.com/datasheets/2N/2N3906.pdf | Q1 | MMBT3906 | Transistor_BJT:MMBT3906 | TO_SOT_Packages_SMD:SOT-23 | https://www.fairchildsemi.com/datasheets/2N/2N3906.pdf | Q1 | MMBT3906 | Transistor_BJT:MMBT3906 | TO_SOT_Packages_SMD:SOT-23 | https://www.fairchildsemi.com/datasheets/2N/2N3906.pdf | Q1 | MMBT3906 | Transistor_BJT:MMBT3906 | TO_SOT_Packages_SMD:SOT-23 | https://www.fairchildsemi.com/datasheets/2N/2N3906.pdf | Q1 | MMBT3906 | Transistor_BJT:MMBT3906 | TO_SOT_Packages_SMD:SOT-23 | https://www.fairchildsemi.com/datasheets/2N/2N3906.pdf | Q1 | MMBT3906 | Transistor_BJT:MMBT3906 | TO_SOT_Packages_SMD:SOT-23 | https://www.fairchildsemi.com/datasheets/2N/2N3906.pdf | Q1 | MMBT3906 | Transistor_BJT:MMBT3906 | TO_SOT_Packages_SMD:SOT-23 | https://www.fairchildsemi.com/datasheets/2N/2N3906.pdf | Q1 | MMBT3906 | Transistor_BJT:MMBT3906 | TO_SOT_Packages_SMD:SOT-23 | https://www.fairchildsemi.com/datasheets/2N/2N3906.pdf | Q1 | MMBT3906 | Transistor_BJT:MMBT3906 | TO_SOT_Packages_SMD:SOT-23 | https://www.fairchildsemi.com/datasheets/2N/2N3906.pdf
R1 | R | Device:R | Resistors_SMD:R_0603_HandSoldering | ~
R2 | R | Device:R | Resistors_SMD:R_0603_HandSoldering | ~
Collated Components:
Item | Qty | Reference(s) | Value | LibPart | Footprint | Datasheet
1 | 1 | D1 | left | Device:LED – green | LEDs:LED_D5.0mm | ~
2 | 1 | D2 | GO | Device:LED – green | LEDs:LED_D5.0mm | ~
3 | 1 | D3 | right | Device:LED – green | LEDs:LED_D5.0mm | ~
4 | 1 | D4 | ready | Device:LED – orange | LEDs:LED_D5.0mm | ~
5 | 1 | D5 | STOP | Device:LED – green | LEDs:LED_D5.0mm | ~
6 | 1 | J1 | Conn_01x06_Male | Connector:Conn_01x06_Male | Socket_Strips:Socket_Strip_Straight_1x06_Pitch2.54mm | ~
7 | 1 | J2 | Conn_01x02_Male | Connector:Conn_01x02_Male | Socket_Strips:Socket_Strip_Straight_1x02_Pitch2.54mm | ~
8 | 1 | J3 | Conn_01x01_Male | Connector:Conn_01x01_Male | Socket_Strips:Socket_Strip_Straight_1x01_Pitch2.54mm | ~
9 | 1 | Q1 | MMBT3906 | Transistor_BJT:MMBT3906 | TO_SOT_Packages_SMD:SOT-23 | https://www.fairchildsemi.com/datasheets/2N/2N3906.pdf
10 | 2 | R1, R2 | R | Device:R | Resistors_SMD:R_0603_HandSoldering | ~

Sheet: motor
Date: | Tue 22 Jan 2019 12:15:49 PM IST
Tool: | Eeschema 5.0.1
Component Count: | 15
Individual Components:
Reference(s) | Value | LibPart | Footprint | Datasheet
C1 | 1uf | Device:C | Capacitors_THT:C_Disc_D3.8mm_W2.6mm_P2.50mm | ~
C2 | 1uf | Device:C | Capacitors_THT:C_Disc_D3.8mm_W2.6mm_P2.50mm | ~
D1 | LED | Device:LED | LEDs:LED_D3.0mm | ~
D2 | LED | Device:LED | LEDs:LED_D3.0mm | ~
D3 | LED | Device:LED | LEDs:LED_D3.0mm | ~
D4 | error | Device:LED | LEDs:LED_D5.0mm | ~
J1 | power | Connector:Conn_01x04_Male | Connectors_JST:JST_EH_B04B-EH-A_04x2.50mm_Straight | ~
J2 | from switches | Connector:Conn_01x04_Male | Connectors_JST:JST_EH_B04B-EH-A_04x2.50mm_Straight | ~
J3 | motor | Connector:Screw_Terminal_01x02 | TerminalBlocks_Phoenix:TerminalBlock_Phoenix_MPT-2.54mm_2pol | ~
J4 | towards uC | Connector:Conn_01x05_Male | Connectors_JST:JST_EH_B05B-EH-A_05x2.50mm_Straight | ~
R1 | 470 | Device:R_US | Resistors_THT:R_Axial_DIN0207_L6.3mm_D2.5mm_P5.08mm_Vertical | ~
R2 | 470 | Device:R_US | Resistors_THT:R_Axial_DIN0207_L6.3mm_D2.5mm_P5.08mm_Vertical | ~
R3 | 470 | Device:R_US | Resistors_THT:R_Axial_DIN0207_L6.3mm_D2.5mm_P5.08mm_Vertical | ~
R4 | 1K | Device:R_US | Resistors_THT:R_Axial_DIN0207_L6.3mm_D2.5mm_P5.08mm_Vertical | ~
U1 | L293D | Driver_Motor:L293D | Housings_DIP:DIP-16_W7.62mm_Socket_LongPads | http://www.ti.com/lit/ds/symlink/l293.pdf
Collated Components:
Item | Qty | Reference(s) | Value | LibPart | Footprint | Datasheet
1 | 2 | C1, C2 | 1uf | Device:C | Capacitors_THT:C_Disc_D3.8mm_W2.6mm_P2.50mm | ~
2 | 3 | D1, D2, D3 | LED | Device:LED – green | LEDs:LED_D3.0mm | ~
3 | 1 | D4 | error | Device:LED – red | LEDs:LED_D5.0mm | ~
4 | 1 | J1 | power | Connector:Conn_01x04_Male | Connectors_JST:JST_EH_B04B-EH-A_04x2.50mm_Straight | ~
5 | 1 | J2 | from switches | Connector:Conn_01x04_Male | Connectors_JST:JST_EH_B04B-EH-A_04x2.50mm_Straight | ~
6 | 1 | J3 | motor | Connector:Screw_Terminal_01x02 | TerminalBlocks_Phoenix:TerminalBlock_Phoenix_MPT-2.54mm_2pol | ~
7 | 1 | J4 | towards uC | Connector:Conn_01x05_Male | Connectors_JST:JST_EH_B05B-EH-A_05x2.50mm_Straight | ~
8 | 3 | R1, R2, R3 | 470 | Device:R_US | Resistors_THT:R_Axial_DIN0207_L6.3mm_D2.5mm_P5.08mm_Vertical | ~
9 | 1 | R4 | 1K | Device:R_US | Resistors_THT:R_Axial_DIN0207_L6.3mm_D2.5mm_P5.08mm_Vertical | ~
10 | 1 | U1 | L293D | Driver_Motor:L293D | Housings_DIP:DIP-16_W7.62mm_Socket_LongPads | http://www.ti.com/lit/ds/symlink/l293.pdf

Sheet: heater
Date: | Tue 22 Jan 2019 12:19:13 PM IST
Tool: | Eeschema 5.0.1
Component Count: | 14
Date Issue | 2019-01-04
Individual Components:
Reference(s) | Value | LibPart | Footprint | Datasheet
D1 | LED | Device:LED | LEDs:LED_0805_HandSoldering | ~
D2 | LED | Device:LED | LEDs:LED_0805_HandSoldering | ~
J1 | power Input | Connector:Conn_01x04_Female | Connectors_JST:JST_XH_B04B-XH-A_04x2.50mm_Straight | ~
J2 | MCUpins | Connector:Conn_01x03_Male | Connectors_JST:JST_XH_B03B-XH-A_03x2.50mm_Straight | ~
J3 | thermistor | Connector:Conn_01x02_Male | Connectors_JST:JST_XH_B02B-XH-A_02x2.50mm_Straight | ~
J4 | fan | Connector:Conn_01x02_Male | Connectors_JST:JST_XH_B02B-XH-A_02x2.50mm_Straight | ~
Q1 | BC517 | Transistor_BJT:BC517 | TO_SOT_Packages_THT:TO-92_Inline_Wide | http://www.fairchildsemi.com/ds/BC/BC517.pdf
Q2 | BC517 | Transistor_BJT:BC517 | TO_SOT_Packages_THT:TO-92_Inline_Wide | http://www.fairchildsemi.com/ds/BC/BC517.pdf
R1 | 470 | Device:R_US | Resistors_SMD:R_0805_HandSoldering | ~
R2 | 27 | Device:R_US | Resistors_THT:R_Axial_Power_L38.0mm_W9.0mm_P40.64mm | ~
R3 | 4.7 | Device:R_US | Resistors_SMD:R_0805_HandSoldering | ~
R4 | 1k | Device:R_US | Resistors_SMD:R_0805_HandSoldering | ~
R5 | 4.7k | Device:R_US | Resistors_SMD:R_0805_HandSoldering | ~
R6 | 470 | Device:R_US | Resistors_SMD:R_0805_HandSoldering | ~
Collated Components:
Item | Qty | Reference(s) | Value | LibPart | Footprint | Datasheet
1 | 2 | D1, D2 | LED | Device:LED | LEDs:LED_0805_HandSoldering | ~
2 | 1 | J1 | power Input | Connector:Conn_01x04_Female | Connectors_JST:JST_XH_B04B-XH-A_04x2.50mm_Straight | ~
3 | 1 | J2 | MCUpins | Connector:Conn_01x03_Male | Connectors_JST:JST_XH_B03B-XH-A_03x2.50mm_Straight | ~
4 | 1 | J3 | thermistor | Connector:Conn_01x02_Male | Connectors_JST:JST_XH_B02B-XH-A_02x2.50mm_Straight | ~
5 | 1 | J4 | fan | Connector:Conn_01x02_Male | Connectors_JST:JST_XH_B02B-XH-A_02x2.50mm_Straight | ~
6 | 2 | Q1, Q2 | BC517 | Transistor_BJT:BC517 | TO_SOT_Packages_THT:TO-92_Inline_Wide | http://www.fairchildsemi.com/ds/BC/BC517.pdf
7 | 2 | R1, R6 | 470 | Device:R_US | Resistors_SMD:R_0805_HandSoldering | ~
8 | 1 | R2 | 27 | Device:R_US | Resistors_THT:R_Axial_Power_L38.0mm_W9.0mm_P40.64mm | ~
9 | 1 | R3 | 4.7 | Device:R_US | Resistors_SMD:R_0805_HandSoldering | ~
10 | 1 | R4 | 1k | Device:R_US | Resistors_SMD:R_0805_HandSoldering | ~
11 | 1 | R5 | 4.7k | Device:R_US | Resistors_SMD:R_0805_HandSoldering | ~

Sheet: switches
Date: | Tue 22 Jan 2019 11:39:28 AM IST
Tool: | Eeschema 5.0.1
Component Count: | 44
Individual Components:
Reference(s) | Value | LibPart | Footprint | Datasheet
D1 | LED | Device:LED | LEDs:LED_1206_HandSoldering | ~
D2 | LED | Device:LED | LEDs:LED_1206_HandSoldering | ~
D3 | LED | Device:LED | LEDs:LED_1206_HandSoldering | ~
D4 | LED | Device:LED | LEDs:LED_1206_HandSoldering | ~
D5 | LED | Device:LED | LEDs:LED_1206_HandSoldering | ~
D6 | LED | Device:LED | LEDs:LED_1206_HandSoldering | ~
D7 | LED | Device:LED | LEDs:LED_1206_HandSoldering | ~
D8 | LED | Device:LED | LEDs:LED_1206_HandSoldering | ~
D9 | LED | Device:LED | LEDs:LED_1206_HandSoldering | ~
D10 | LED | Device:LED | LEDs:LED_1206_HandSoldering | ~
J1 | switchesOut | Connector:Conn_01x12_Male | Socket_Strips:Socket_Strip_Straight_1x12_Pitch2.54mm | ~
J2 | Conn_01x01_Female | Connector:Conn_01x01_Female | Wire_Pads:SolderWirePad_single_SMD_5x10mm | ~
J3 | Conn_01x01_Female | Connector:Conn_01x01_Female | Wire_Pads:SolderWirePad_single_SMD_5x10mm | ~
J4 | Conn_01x01_Female | Connector:Conn_01x01_Female | Wire_Pads:SolderWirePad_single_SMD_5x10mm | ~
J5 | Conn_01x01_Female | Connector:Conn_01x01_Female | Wire_Pads:SolderWirePad_single_SMD_5x10mm | ~
J6 | Conn_01x01_Female | Connector:Conn_01x01_Female | Wire_Pads:SolderWirePad_single_SMD_5x10mm | ~
J7 | Conn_01x01_Female | Connector:Conn_01x01_Female | Wire_Pads:SolderWirePad_single_SMD_5x10mm | ~
J8 | Conn_01x01_Female | Connector:Conn_01x01_Female | Wire_Pads:SolderWirePad_single_SMD_5x10mm | ~
J9 | Conn_01x01_Female | Connector:Conn_01x01_Female | Wire_Pads:SolderWirePad_single_SMD_5x10mm | ~
J10 | Conn_01x01_Female | Connector:Conn_01x01_Female | Wire_Pads:SolderWirePad_single_SMD_5x10mm | ~
J11 | Conn_01x01_Female | Connector:Conn_01x01_Female | Wire_Pads:SolderWirePad_single_SMD_5x10mm | ~
J12 | Conn_01x01_Female | Connector:Conn_01x01_Female | Wire_Pads:SolderWirePad_single_SMD_5x10mm | ~
Q1 | 2N7002 | Transistor_FET:2N7002 | TO_SOT_Packages_SMD:SOT-23 | https://www.fairchildsemi.com/datasheets/2N/2N7002.pdf
Q2 | 2N7002 | Transistor_FET:2N7002 | TO_SOT_Packages_SMD:SOT-23 | https://www.fairchildsemi.com/datasheets/2N/2N7002.pdf
Q3 | 2N7002 | Transistor_FET:2N7002 | TO_SOT_Packages_SMD:SOT-23 | https://www.fairchildsemi.com/datasheets/2N/2N7002.pdf
Q4 | 2N7002 | Transistor_FET:2N7002 | TO_SOT_Packages_SMD:SOT-23 | https://www.fairchildsemi.com/datasheets/2N/2N7002.pdf
Q5 | 2N7002 | Transistor_FET:2N7002 | TO_SOT_Packages_SMD:SOT-23 | https://www.fairchildsemi.com/datasheets/2N/2N7002.pdf
Q6 | 2N7002 | Transistor_FET:2N7002 | TO_SOT_Packages_SMD:SOT-23 | https://www.fairchildsemi.com/datasheets/2N/2N7002.pdf
R1 | R_US | Device:R_US | Resistors_SMD:R_0805_HandSoldering | ~
R2 | R_US | Device:R_US | Resistors_SMD:R_0805_HandSoldering | ~
R3 | R_US | Device:R_US | Resistors_SMD:R_0805_HandSoldering | ~
R4 | R_US | Device:R_US | Resistors_SMD:R_0805_HandSoldering | ~
R5 | R_US | Device:R_US | Resistors_SMD:R_0805_HandSoldering | ~
R6 | R_US | Device:R_US | Resistors_SMD:R_0805_HandSoldering | ~
R7 | R_US | Device:R_US | Resistors_SMD:R_0805_HandSoldering | ~
R8 | R_US | Device:R_US | Resistors_SMD:R_0805_HandSoldering | ~
R9 | R_US | Device:R_US | Resistors_SMD:R_0805_HandSoldering | ~
R10 | R_US | Device:R_US | Resistors_SMD:R_0805_HandSoldering | ~
R11 | R_US | Device:R_US | Resistors_SMD:R_0805_HandSoldering | ~
R12 | R_US | Device:R_US | Resistors_SMD:R_0805_HandSoldering | ~
R13 | R_US | Device:R_US | Resistors_SMD:R_0805_HandSoldering | ~
R14 | R_US | Device:R_US | Resistors_SMD:R_0805_HandSoldering | ~
R15 | R_US | Device:R_US | Resistors_SMD:R_0805_HandSoldering | ~
R16 | R_US | Device:R_US | Resistors_SMD:R_0805_HandSoldering | ~
Collated Components:
Item | Qty | Reference(s) | Value | LibPart | Footprint | Datasheet
1 | 10 | D1, D2, D3, D4, D5, D6, D7, D8, D9, D10 | LED | Device:LED | LEDs:LED_1206_HandSoldering | ~
2 | 1 | J1 | switchesOut | Connector:Conn_01x12_Male | Socket_Strips:Socket_Strip_Straight_1x12_Pitch2.54mm | ~
3 | 11 | J2, J3, J4, J5, J6, J7, J8, J9, J10, J11, J12 | Conn_01x01_Female | Connector:Conn_01x01_Female | Wire_Pads:SolderWirePad_single_SMD_5x10mm | ~
4 | 6 | Q1, Q2, Q3, Q4, Q5, Q6 | 2N7002 | Transistor_FET:2N7002 | TO_SOT_Packages_SMD:SOT-23 | https://www.fairchildsemi.com/datasheets/2N/2N7002.pdf
5 | 16 | R1, R2, R3, R4, R5, R6, R7, R8, R9, R10, R11, R12, R13, R14, R15, R16 | R_US | Device:R_US | Resistors_SMD:R_0805_HandSoldering | ~
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

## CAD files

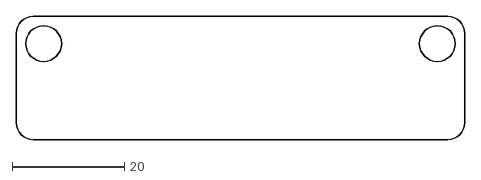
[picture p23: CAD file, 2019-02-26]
OpenPLC_modules/heater/heaterBoard.dxf
80.0 x 22.0

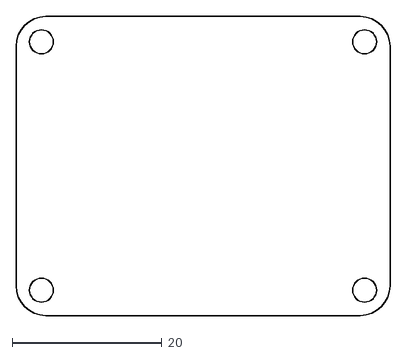
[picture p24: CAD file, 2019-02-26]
OpenPLC_modules/motor/motorCutlines.dxf
50.0 x 40.0

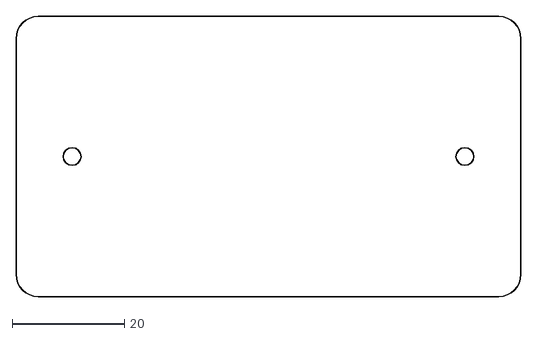
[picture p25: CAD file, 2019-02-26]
OpenPLC_modules/switches/cutlineSwitch.dxf
90.0 x 50.0

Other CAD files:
OpenPLC_modules/heater/boardOutline.fcstd
OpenPLC_modules/motor/motorPCB.fcstd
OpenPLC_modules/switches/boardoutlineSwithes.fcstd

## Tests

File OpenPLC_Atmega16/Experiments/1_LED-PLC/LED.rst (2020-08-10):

Light Emitting Diode
====================

Overview
--------

LEDs (light emitting diodes) are used in all sorts of 
clever things which is why we have induced them in the kit.
We will start off with something very simple, turning one 
ON and OFF, repeatedly,producing a pleasant blinking effect. 
In the ld micro insert coil and insert contacts and also 
insert Ton and Toff and give particular timings for both. 
Burn the code to OpenPLC and watch the output

Components required
-------------------

OpenPLC board

blinking of LED
---------------

For blinking of LED we use timers in ldmicro, On timer(Ton) and Off timer(Toff). The LED is connected to pin 35 on the board. 
The code blinkin.ld illustrates above logic.

switch on LED
-------------

We can control on/off LED by using an input to the PLC. The input switch is connected to pin 1 and LED is connected to the same pin 35.
The code for this experiment is switch-led.ld

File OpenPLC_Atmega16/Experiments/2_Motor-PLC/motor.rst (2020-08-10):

DC motor
========

Overview
--------

DC Motor, like the general purpose motors, are used in providing high RPM for rotation purposes, like for a pulley or in lifting action. Motors, are generally heavy duty, which means, connecting it directly to the controller pins may end up frying it up! So, to source higher
current, transistors or motor driver ICs are used. These are great as they can be easily used to turn your motor in either direction, just by giving digital high or low to the input pins of L293D Motor Driver IC. The easy part is, controlling the speed can be done by just changing the voltage bias given to the driver IC. 

Components required
-------------------

OpenPLC board

DC motor

Switch ON motor
---------------

In this experiment using an input switch, PLC turns on the motor connected to it. Motor is driven by l293d as explained above. L293d inputs are connected to controller pin number 19 and 20. The switch is connected to pin number 1.

To run motor we always need two coils on ldmicro and one should be 'set' and other 'reset'. If we swap the coil status motor will run in opposite direction.

Motor-on-off
------------

We now know how to turn on a motor, Similarly we can turn it Off by giving another input. To stop motor, status of both the coils should be Reset, So in new rung we can give a switch and reset both the coils.
Another switch is connected to pin number 2.

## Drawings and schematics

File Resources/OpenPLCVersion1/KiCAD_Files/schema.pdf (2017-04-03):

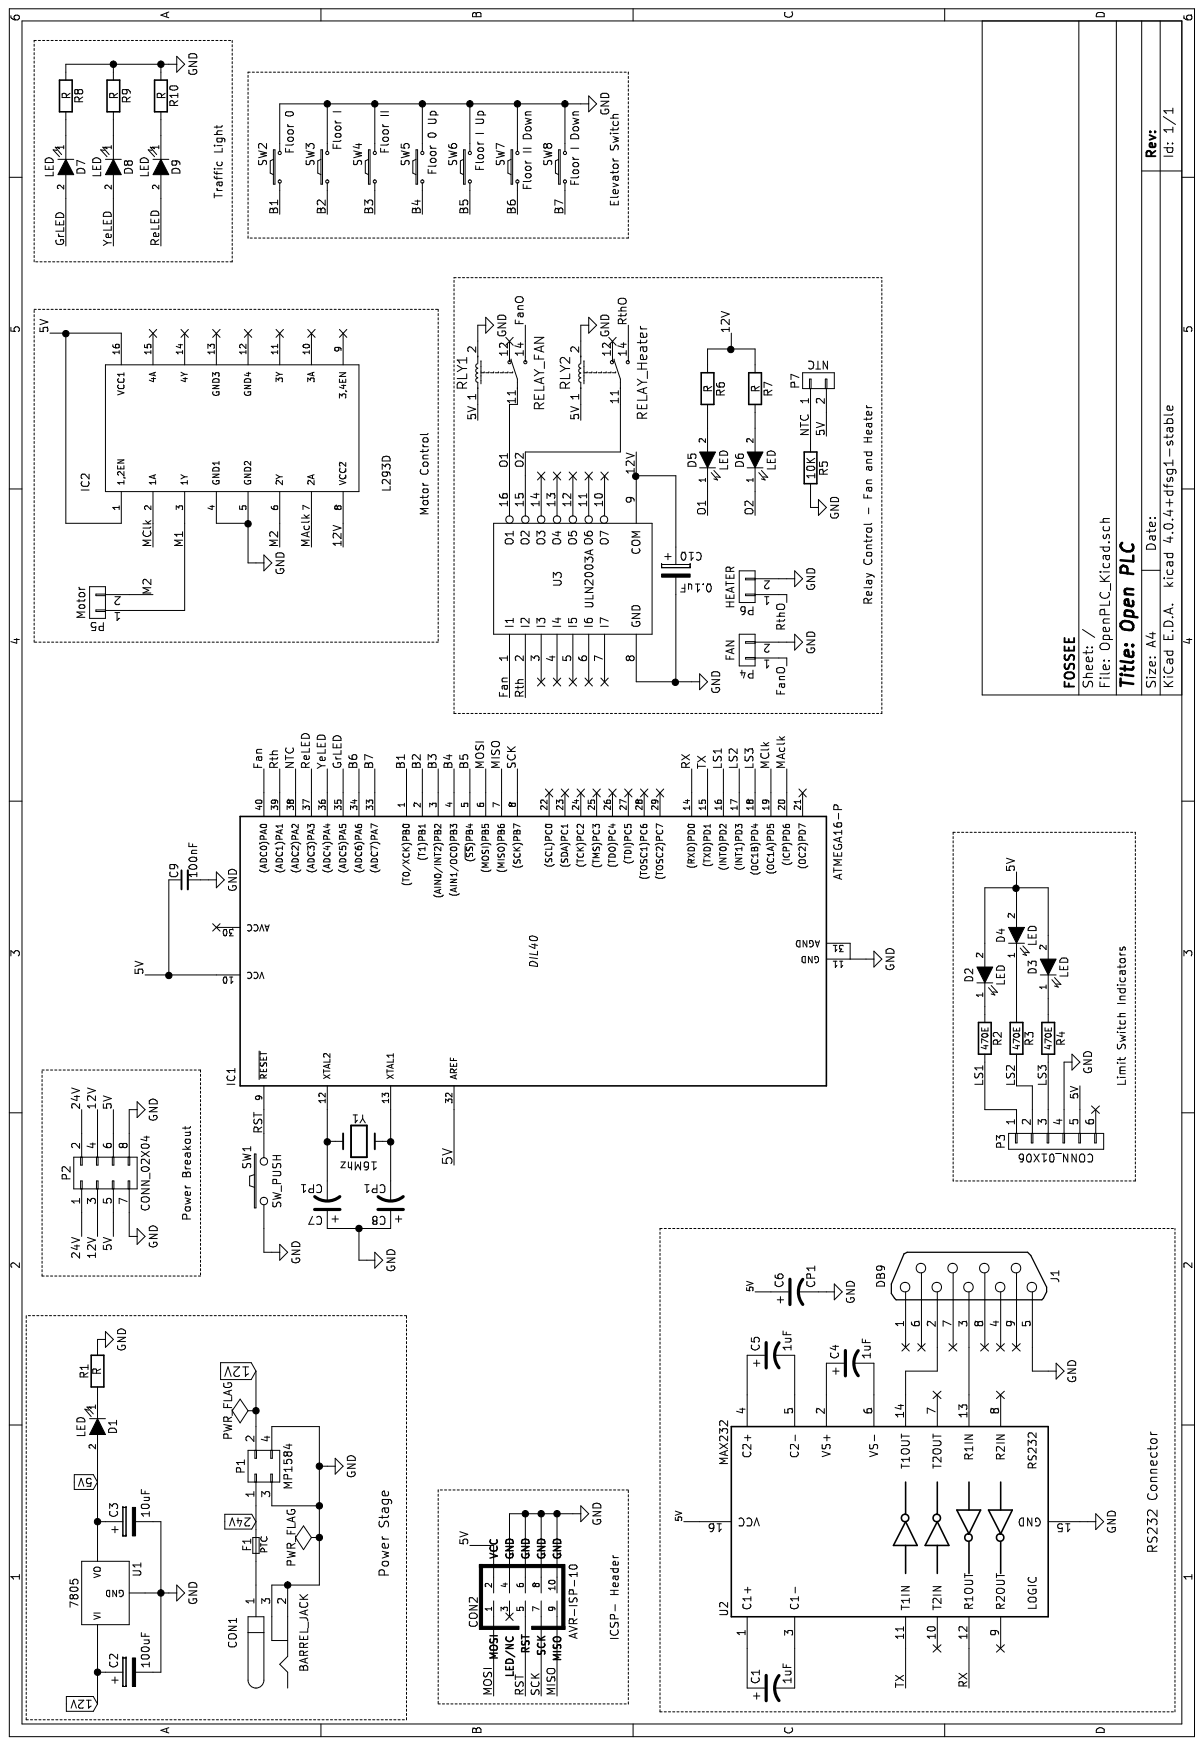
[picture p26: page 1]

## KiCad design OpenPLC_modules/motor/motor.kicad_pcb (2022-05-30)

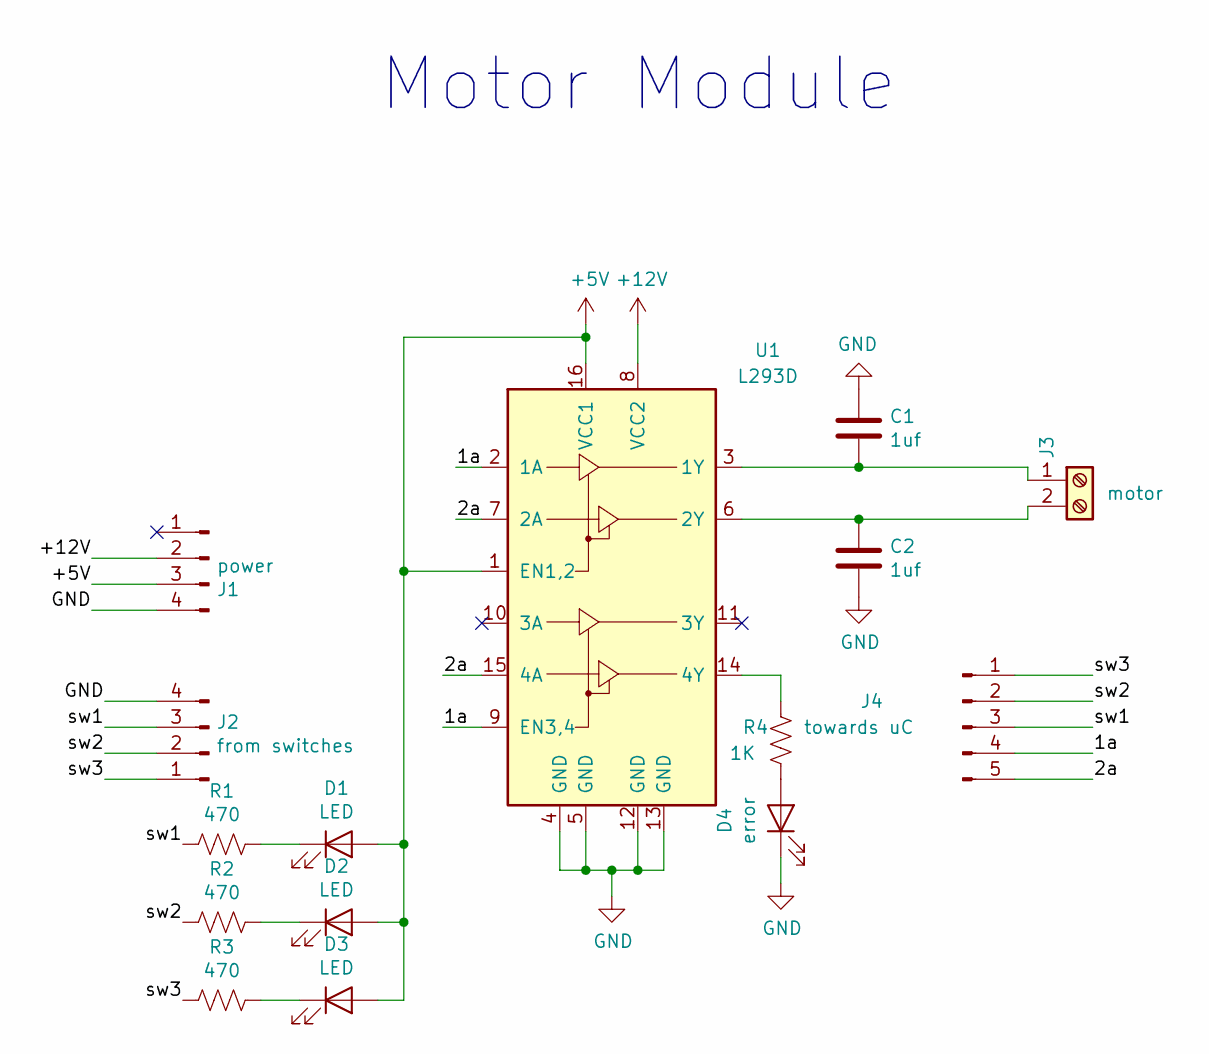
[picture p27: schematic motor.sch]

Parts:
C1, C2: 1uf; C_Disc_D3.8mm_W2.6mm_P2.50mm
D1, D2, D3: LED; LED_D3.0mm
D4: error; LED_D5.0mm
J1: power; JST_EH_B04B-EH-A_04x2.50mm_Straight
J2: from switches; JST_EH_B04B-EH-A_04x2.50mm_Straight
J3: motor; TerminalBlock_Phoenix_MPT-2.54mm_2pol
J4: towards uC; JST_EH_B05B-EH-A_05x2.50mm_Straight
R1, R2, R3: 470; R_Axial_DIN0207_L6.3mm_D2.5mm_P5.08mm_Vertical
R4: 1K; R_Axial_DIN0207_L6.3mm_D2.5mm_P5.08mm_Vertical
U1: L293D; DIP-16_W7.62mm_Socket_LongPads

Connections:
+5V: D1.2 (A), D2.2 (A), D3.2 (A), J1.3, U1.1 (EN1,2), U1.16 (VCC1)
+12V: J1.2, U1.8 (VCC2)
/1a: J4.4, U1.2 (1A), U1.9 (EN3,4)
/2a: J4.5, U1.7 (2A), U1.15 (4A)
/sw1: J2.3, J4.3, R1.1
/sw2: J2.2, J4.2, R2.1
/sw3: J2.1, J4.1, R3.1
GND: C1.1, C2.2, D4.1 (K), J1.4, J2.4, U1.4 (GND), U1.5 (GND), U1.12 (GND), U1.13 (GND)
unnamed: C1.2, J3.1, U1.3 (1Y)
unnamed: C2.1, J3.2, U1.6 (2Y)
unnamed: D1.1 (K), R1.2
unnamed: D2.1 (K), R2.2
unnamed: D3.1 (K), R3.2
unnamed: D4.2 (A), R4.2
unnamed: R4.1, U1.14 (4Y)

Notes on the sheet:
Motor Module

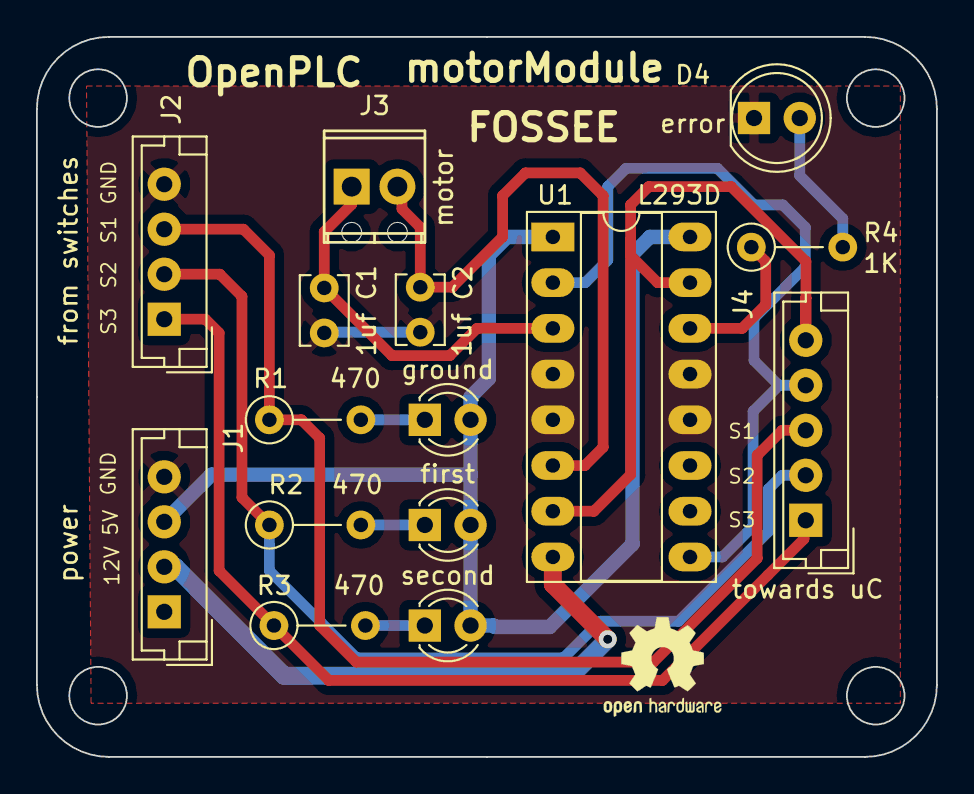
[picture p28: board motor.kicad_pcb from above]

Board: 2 copper layers, 50.0 x 40.0 mm, 15 parts (0 on the bottom side), 15 nets.

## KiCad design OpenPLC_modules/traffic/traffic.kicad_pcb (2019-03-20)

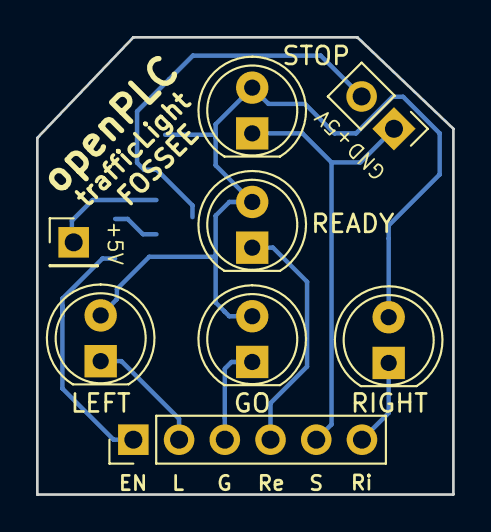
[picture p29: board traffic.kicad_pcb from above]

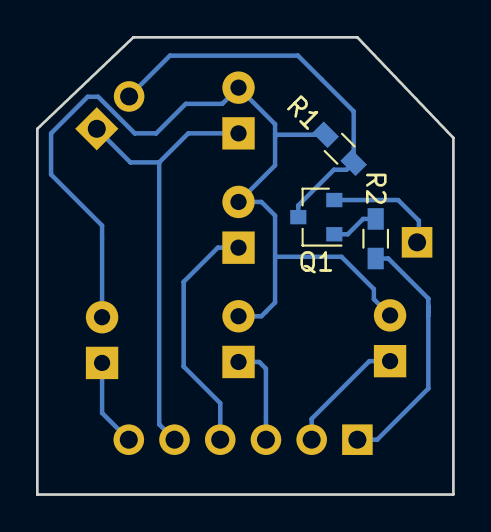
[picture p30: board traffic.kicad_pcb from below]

Board: 2 copper layers, 23.1 x 25.4 mm, 11 parts (3 on the bottom side), 10 nets.

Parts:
D1: LEFT; LED_D5.0mm
D2: GO; LED_D5.0mm
D3: RIGHT; LED_D5.0mm
D4: READY; LED_D5.0mm
D5: STOP; LED_D5.0mm
J1: Conn_01x06_Male; Socket_Strip_Straight_1x06_Pitch2.54mm
J2: Conn_01x02_Male; Socket_Strip_Straight_1x02_Pitch2.54mm
J3: Conn_01x01_Male; Socket_Strip_Straight_1x01_Pitch2.54mm
Q1: MMBT3906; SOT-23
R1, R2: R; R_0603_HandSoldering

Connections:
+5C: J3.1, Q1.2
unnamed: D1.1, J1.2
unnamed: D1.2, D2.2, D3.2, D4.2, D5.2, R1.1
unnamed: D2.1, J1.3
unnamed: D3.1, J1.6
unnamed: D4.1, J1.4
unnamed: D5.1, J1.5, J2.1
unnamed: J1.1, R2.2
unnamed: J2.2, Q1.3, R1.2
unnamed: Q1.1, R2.1

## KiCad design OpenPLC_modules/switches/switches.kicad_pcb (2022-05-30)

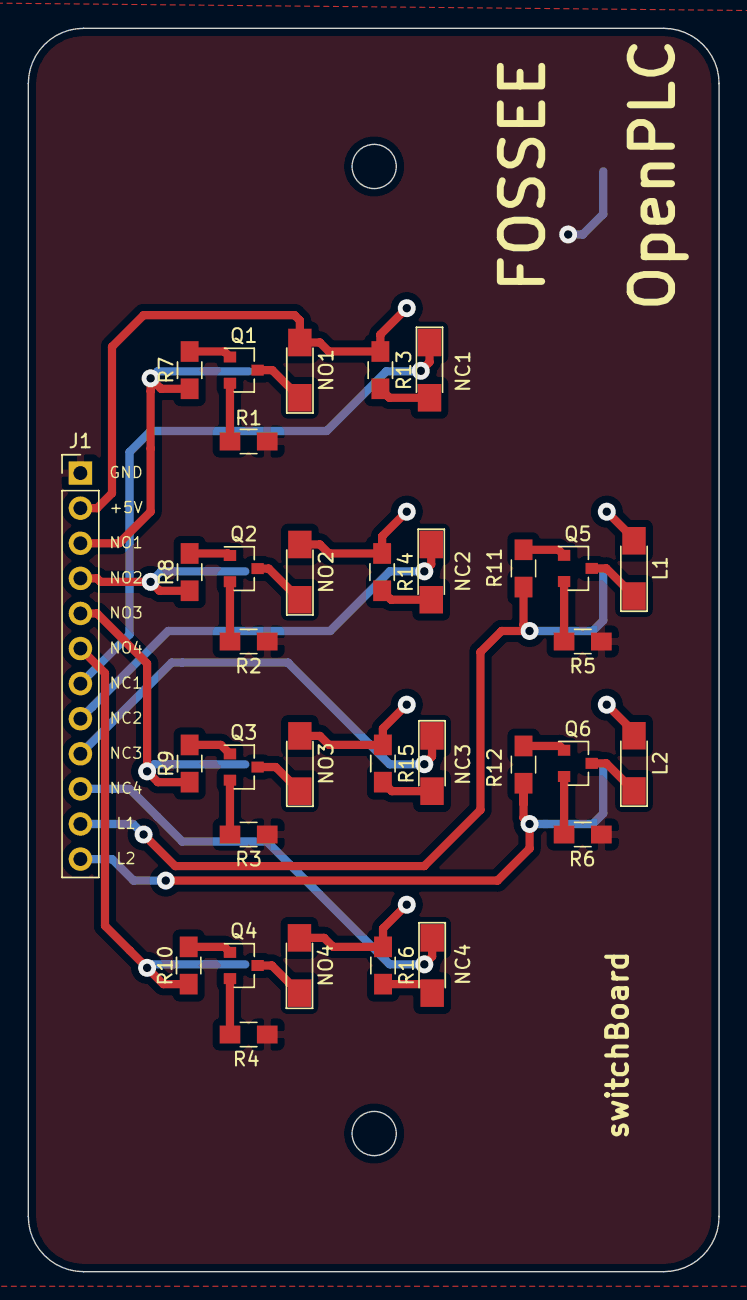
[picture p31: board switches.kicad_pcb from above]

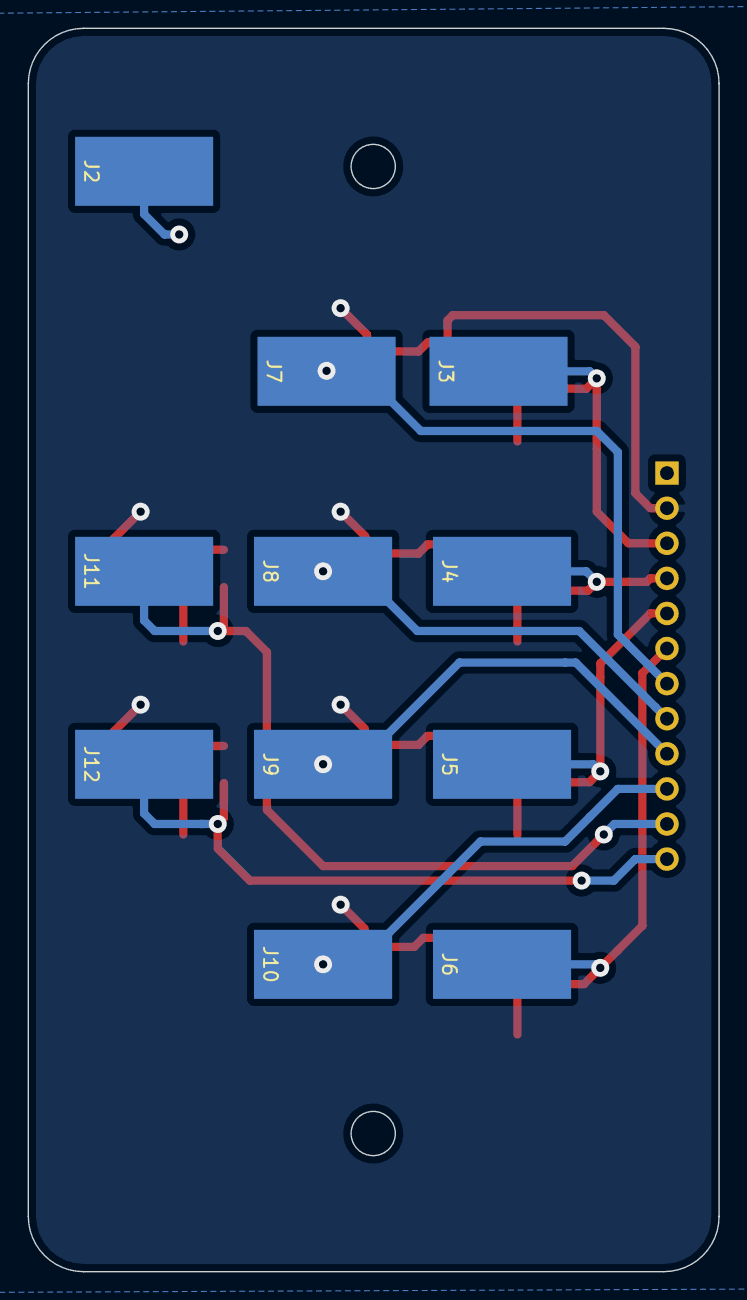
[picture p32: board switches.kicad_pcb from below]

Board: 2 copper layers, 50.0 x 90.0 mm, 44 parts (11 on the bottom side), 34 nets.

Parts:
D1: NO1; LED_1206_HandSoldering
D2: NO2; LED_1206_HandSoldering
D3: NO3; LED_1206_HandSoldering
D4: NO4; LED_1206_HandSoldering
D5: L1; LED_1206_HandSoldering
D6: L2; LED_1206_HandSoldering
D7: NC1; LED_1206_HandSoldering
D8: NC2; LED_1206_HandSoldering
D9: NC3; LED_1206_HandSoldering
D10: NC4; LED_1206_HandSoldering
J1: switchesOut; Socket_Strip_Straight_1x12_Pitch2.54mm
J2, J3, J4, J5, J6, J7, J8, J9, J10, J11, J12: Conn_01x01_Female; SolderWirePad_single_SMD_5x10mm
Q1, Q2, Q3, Q4, Q5, Q6: 2N7002; SOT-23
R1, R2, R3, R4, R5, R6, R7, R8, R9, R10, R11, R12, R13, R14, R15, R16: R_US; R_0805_HandSoldering

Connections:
+5V: D1.2, D2.2, D3.2, D4.2, D5.2, D6.2, J1.2, R13.1, R14.1, R15.1, R16.1
/s1: J1.3, J3.1, R7.1
/s2: J1.4, J4.1, R8.1
/s3: J1.5, J5.1, R9.1
/s4: J1.6, J6.1, R10.1
/s5: D7.1, J1.7, J7.1
/s6: D8.1, J1.8, J8.1
/s7: D9.1, J1.9, J9.1
/s8: D10.1, J1.10, J10.1
/s9: J1.11, J11.1, R11.1
/s10: J1.12, J12.1, R12.1
GND: J1.1, J2.1, R1.2, R2.2, R3.2, R4.2, R5.2, R6.2
unnamed: D1.1, Q1.3
unnamed: D2.1, Q2.3
unnamed: D3.1, Q3.3
unnamed: D4.1, Q4.3
unnamed: D5.1, Q5.3
unnamed: D6.1, Q6.3
unnamed: D7.2, R13.2
unnamed: D8.2, R14.2
unnamed: D9.2, R15.2
unnamed: D10.2, R16.2
unnamed: Q1.1, R7.2
unnamed: Q1.2, R1.1
unnamed: Q2.1, R8.2
unnamed: Q2.2, R2.1
unnamed: Q3.1, R9.2
unnamed: Q3.2, R3.1
unnamed: Q4.1, R10.2
unnamed: Q4.2, R4.1
unnamed: Q5.1, R11.2
unnamed: Q5.2, R5.1
unnamed: Q6.1, R12.2
unnamed: Q6.2, R6.1

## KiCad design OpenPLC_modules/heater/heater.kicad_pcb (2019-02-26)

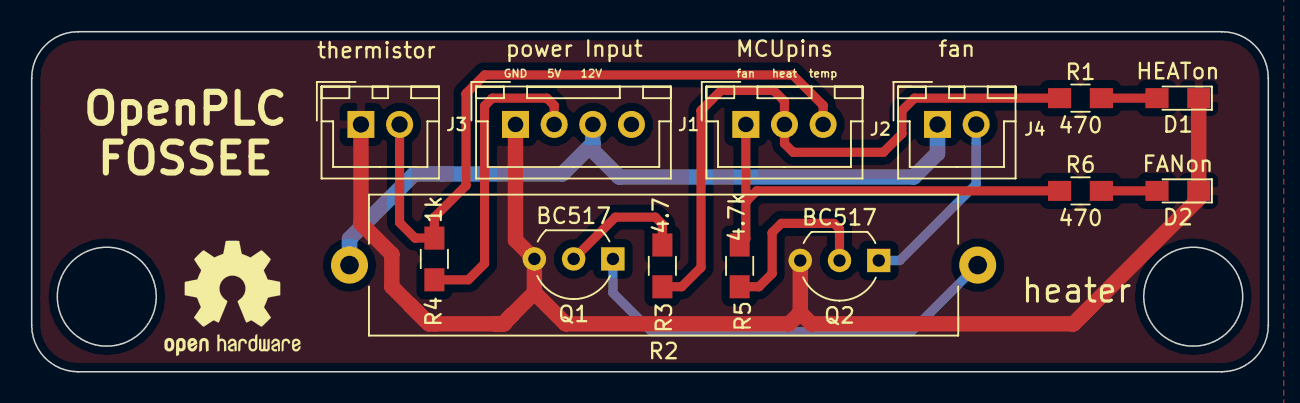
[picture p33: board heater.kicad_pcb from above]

Board: 2 copper layers, 80.0 x 22.0 mm, 14 parts (0 on the bottom side), 12 nets.

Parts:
D1: HEATon; LED_0805_HandSoldering
D2: FANon; LED_0805_HandSoldering
J1: power Input; JST_XH_B04B-XH-A_04x2.50mm_Straight
J2: MCUpins; JST_XH_B03B-XH-A_03x2.50mm_Straight
J3: thermistor; JST_XH_B02B-XH-A_02x2.50mm_Straight
J4: fan; JST_XH_B02B-XH-A_02x2.50mm_Straight
Q1, Q2: BC517; TO-92_Inline_Wide
R1, R6: 470; R_0805_HandSoldering
R2: 27; R_Axial_Power_L38.0mm_W9.0mm_P40.64mm
R3: 4.7; R_0805_HandSoldering
R4: 1k; R_0805_HandSoldering
R5: 4.7k; R_0805_HandSoldering

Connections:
+5V: J1.2, R4.1
+12V: J1.3, J4.1, R2.2
/fromMcuF: J2.1, R5.2, R6.1
/fromMcuR: J2.2, R1.1, R3.2
/toMcu: J2.3, J3.2, R4.2
GND: D1.1, D2.1, J1.1, J3.1, Q1.3, Q2.3
unnamed: D1.2, R1.2
unnamed: D2.2, R6.2
unnamed: J4.2, Q2.1
unnamed: Q1.1, R2.1
unnamed: Q1.2, R3.1
unnamed: Q2.2, R5.1

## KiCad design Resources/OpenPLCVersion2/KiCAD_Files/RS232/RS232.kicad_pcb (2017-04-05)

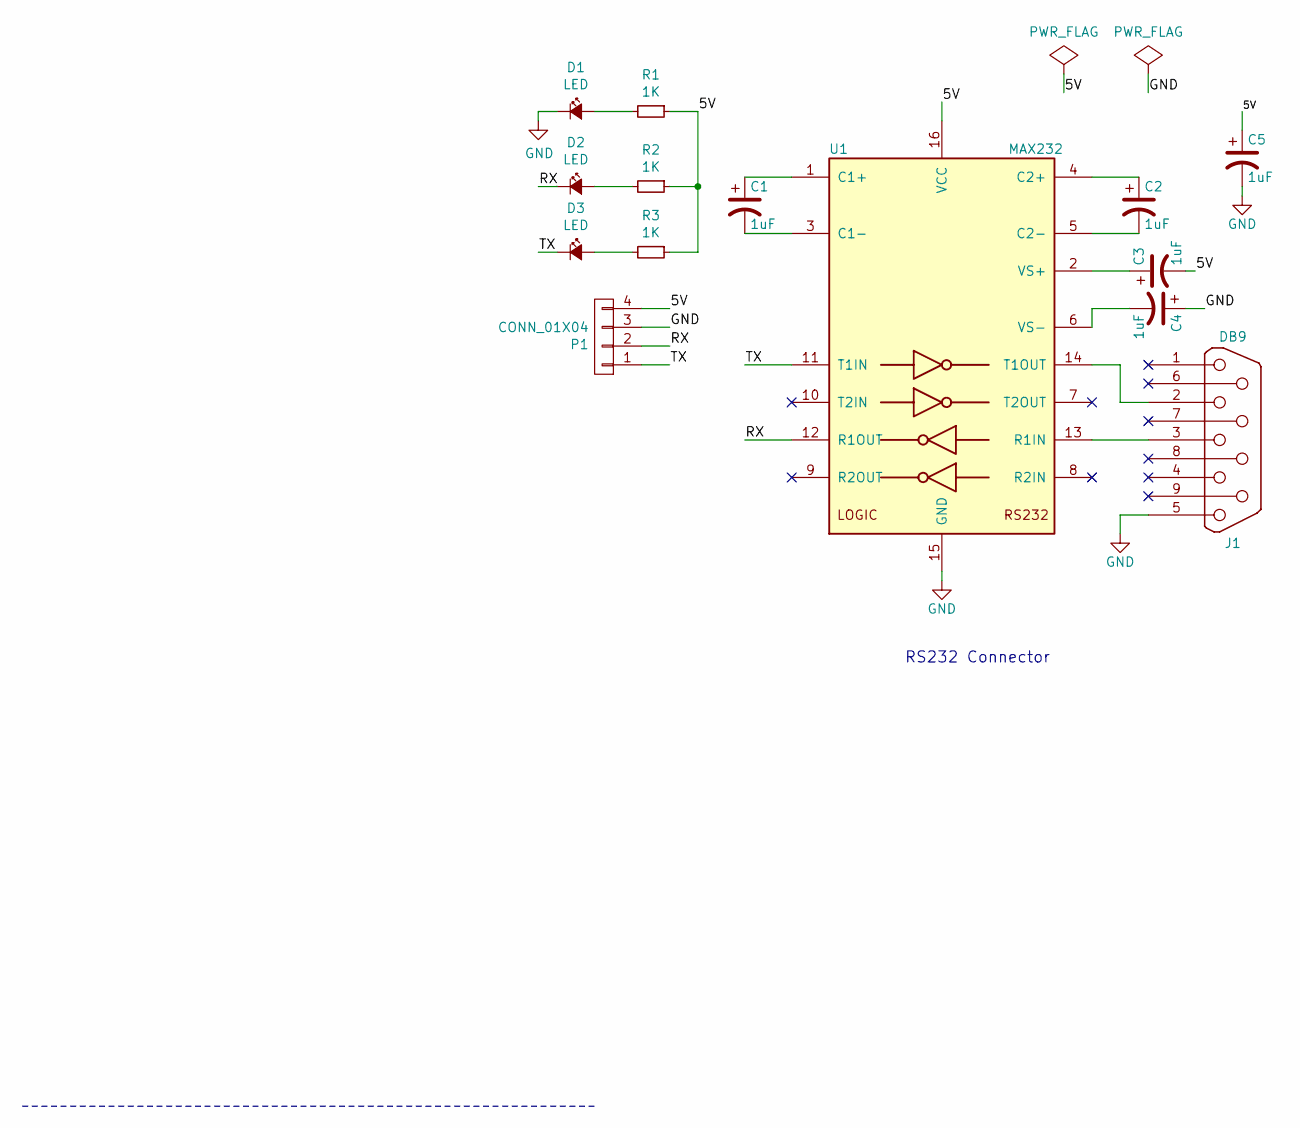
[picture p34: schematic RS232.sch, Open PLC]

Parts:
C1, C2, C3, C4, C5: 1uF; C_0805_HandSoldering
D1, D2, D3: LED; C_0805
J1: DB9; DB9FC
P1: CONN_01X04; Pin_Header_Angled_1x04
R1, R2, R3: 1K; C_0805
U1: MAX232; DIP-16_W7.62mm_LongPads

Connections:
/5V: C3.2, C5.1, P1.4, R1.1, R2.1, R3.1, U1.16 (VCC)
/RX: D2.1 (K), P1.2, U1.12 (R1OUT)
/TX: D3.1 (K), P1.1, U1.11 (T1IN)
GND: C4.1, C5.2, D1.1 (K), J1.5, P1.3, U1.15 (GND)
unnamed: C1.1, U1.1 (C1+)
unnamed: C1.2, U1.3 (C1-)
unnamed: C2.1, U1.4 (C2+)
unnamed: C2.2, U1.5 (C2-)
unnamed: C3.1, U1.2 (VS+)
unnamed: C4.2, U1.6 (VS-)
unnamed: D1.2 (A), R1.2
unnamed: D2.2 (A), R2.2
unnamed: D3.2 (A), R3.2
unnamed: J1.2, U1.14 (T1OUT)
unnamed: J1.3, U1.13 (R1IN)

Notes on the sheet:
RS232 Connector

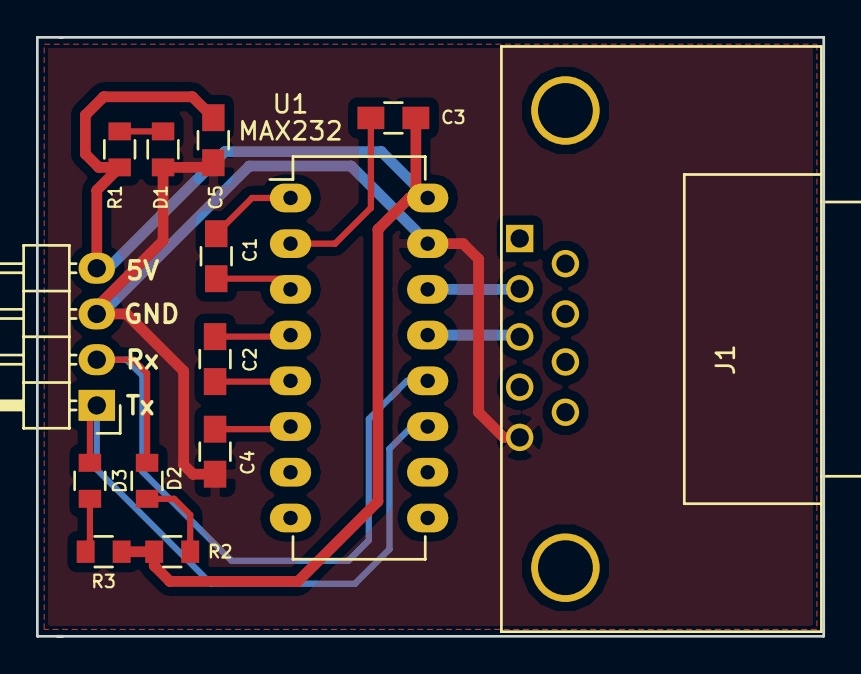
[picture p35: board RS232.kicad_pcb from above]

Board: 2 copper layers, 43.7 x 33.3 mm, 14 parts (0 on the bottom side), 15 nets.

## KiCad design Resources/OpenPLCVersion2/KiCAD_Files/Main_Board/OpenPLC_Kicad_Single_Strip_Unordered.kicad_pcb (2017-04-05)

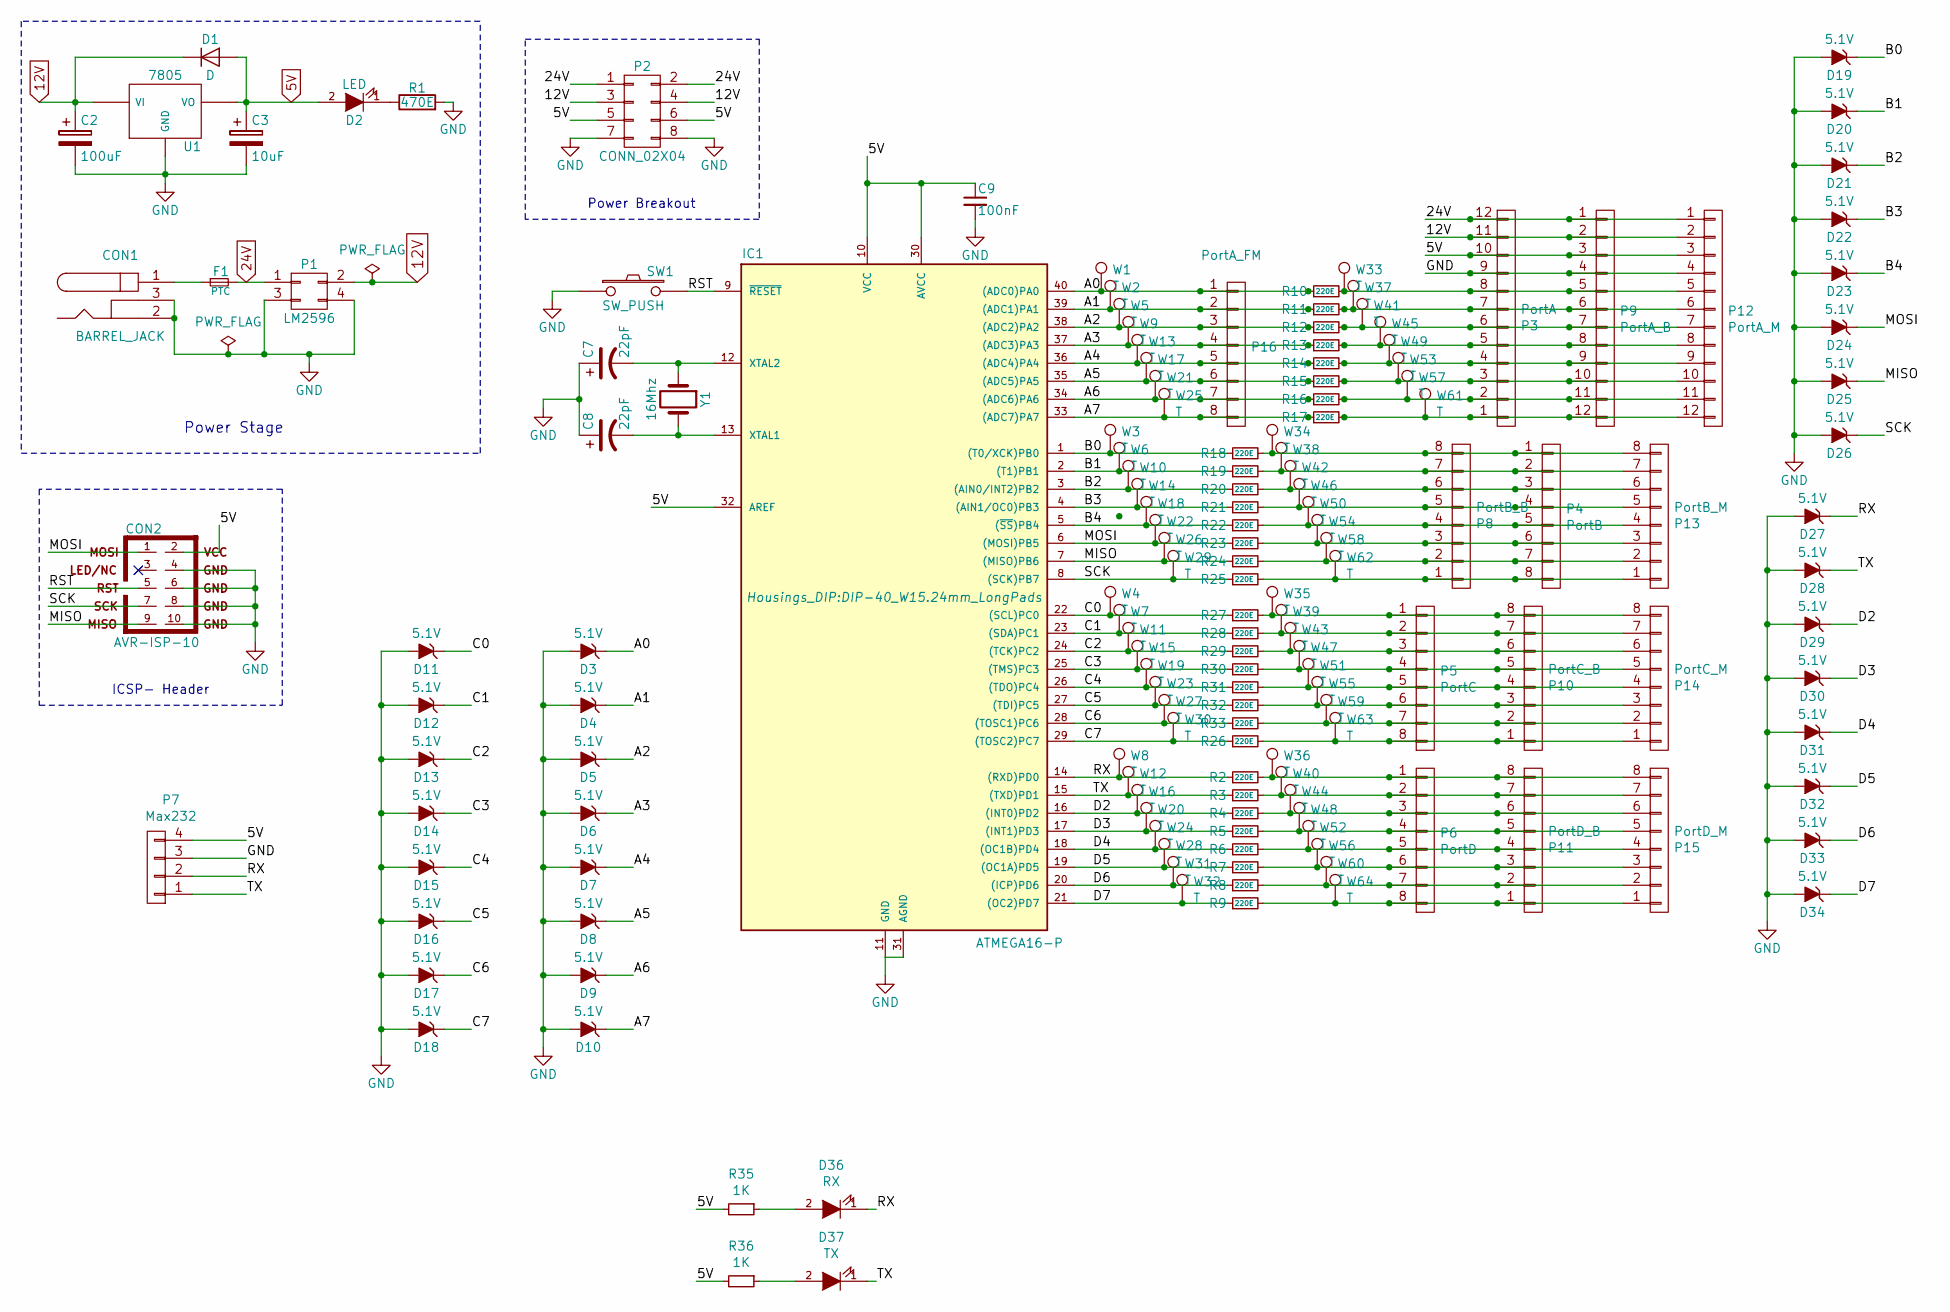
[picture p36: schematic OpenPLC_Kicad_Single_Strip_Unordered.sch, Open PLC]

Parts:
C2: 100uF; C_Radial_D5_L11_P2.5
C3: 10uF; C_Radial_D5_L11_P2.5
C7, C8: 22pF; C_0805
C9: 100nF; C_0805
CON1: BARREL_JACK
CON2: AVR-ISP-10; IDC_Header_Straight_10pins
D1: D; Diode_DO-41_SOD81_Horizontal_RM10
D2: LED; LED_0805
D3, D4, D5, D6, D7, D8, D9, D10, D11, D12, D13, D14, D15, D16, D17, D18, D19, D20, D21, D22, D23, D24, D25, D26, D27, D28, D29, D30, D31, D32, D33, D34: 5.1V; MiniMELF_Standard
D36: RX; LED_0805
D37: TX; LED_0805
F1: PTC; Resistor_Horizontal_RM10mm
IC1: ATMEGA16-P; DIP-40_W15.24mm_LongPads
P1: LM2596; LM2596s_New
P2: CONN_02X04; Socket_Strip_Straight_2x04
P3: PortA; TerminalBlock_Pheonix_MKDS1.5-12pol
P4: PortB; TerminalBlock_Pheonix_MKDS1.5-8pol
P5: PortC; TerminalBlock_Pheonix_MKDS1.5-8pol
P6: PortD; TerminalBlock_Pheonix_MKDS1.5-8pol
P7: Max232; Socket_Strip_Angled_1x04
P8: PortB_B; Socket_Strip_Straight_1x08
P9: PortA_B; Socket_Strip_Straight_1x12
P10: PortC_B; Socket_Strip_Straight_1x08
P11: PortD_B; Socket_Strip_Straight_1x08
P12: PortA_M; Pin_Header_Straight_1x12
P13: PortB_M; Pin_Header_Straight_1x08
P14: PortC_M; Pin_Header_Straight_1x08
P15: PortD_M; Pin_Header_Straight_1x08
P16: PortA_FM; Socket_Strip_Straight_1x08
R1: 470E; R_0805
R2, R3, R4, R5, R6, R7, R8, R9, R10, R11, R12, R13, R14, R15, R16, R17, R18, R19, R20, R21, R22, R23, R24, R25, R26, R27, R28, R29, R30, R31, R32, R33: 220E; R_0805
R35, R36: 1K; R_0805
SW1: SW_PUSH; SW_SPST_B3SL-1002P
U1: 7805; TO-220_Neutral123_Vertical
W1, W2, W3, W4, W5, W6, W7, W8, W9, W10, W11, W12, W13, W14, W15, W16, W17, W18, W19, W20, W21, W22, W23, W24, W25, W26, W27, W28, W29, W30, W31, W32, W33, W34, W35, W36, W37, W38, W39, W40, W41, W42, W43, W44, W45, W46, W47, W48, W49, W50, W51, W52, W53, W54, W55, W56, W57, W58, W59, W60, W61, W62, W63, W64: T; SolderWirePad_single_0-8mmDrill
Y1: 16Mhz; Crystal_HC49-U_Vertical

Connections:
5V: C3.1, C9.1, CON2.2, D1.2 (A), D2.2 (A), IC1.10 (VCC), IC1.30 (AVCC), IC1.32 (AREF), P2.5, P2.6, P3.10, P7.4, P9.3, P12.3, R35.2, R36.2, U1.3 (VO)
12V: C2.1, D1.1 (K), P1.2, P2.3, P2.4, P3.11, P9.2, P12.2, U1.1 (VI)
24V: F1.2, P1.1, P2.1, P2.2, P3.12, P9.1, P12.1
/A0: D3.1 (K), IC1.40 ((ADC0)PA0), P16.1, R10.1, W1.1
/A1: D4.1 (K), IC1.39 ((ADC1)PA1), P16.2, R11.1, W2.1
/A2: D5.1 (K), IC1.38 ((ADC2)PA2), P16.3, R12.1, W5.1
/A3: D6.1 (K), IC1.37 ((ADC3)PA3), P16.4, R13.1, W9.1
/A4: D7.1 (K), IC1.36 ((ADC4)PA4), P16.5, R14.1, W13.1
/A5: D8.1 (K), IC1.35 ((ADC5)PA5), P16.6, R15.1, W17.1
/A6: D9.1 (K), IC1.34 ((ADC6)PA6), P16.7, R16.1, W21.1
/A7: D10.1 (K), IC1.33 ((ADC7)PA7), P16.8, R17.1, W25.1
/B0: D19.1 (K), IC1.1 ((T0/XCK)PB0), R18.1, W3.1
/B1: D20.1 (K), IC1.2 ((T1)PB1), R19.1, W6.1
/B2: D21.1 (K), IC1.3 ((AIN0/INT2)PB2), R20.1, W10.1
/B3: D22.1 (K), IC1.4 ((AIN1/OC0)PB3), R21.1, W14.1
/B4: D23.1 (K), IC1.5 ((~SS~)PB4), R22.1, W18.1
/C0: D11.1 (K), IC1.22 ((SCL)PC0), R27.1, W4.1
/C1: D12.1 (K), IC1.23 ((SDA)PC1), R28.1, W7.1
/C2: D13.1 (K), IC1.24 ((TCK)PC2), R29.1, W11.1
/C3: D14.1 (K), IC1.25 ((TMS)PC3), R30.1, W15.1
/C4: D15.1 (K), IC1.26 ((TDO)PC4), R31.1, W19.1
/C5: D16.1 (K), IC1.27 ((TDI)PC5), R32.1, W23.1
/C6: D17.1 (K), IC1.28 ((TOSC1)PC6), R33.1, W27.1
/C7: D18.1 (K), IC1.29 ((TOSC2)PC7), R26.1, W30.1
/D2: D29.1 (K), IC1.16 ((INT0)PD2), R4.1, W16.1
/D3: D30.1 (K), IC1.17 ((INT1)PD3), R5.1, W20.1
/D4: D31.1 (K), IC1.18 ((OC1B)PD4), R6.1, W24.1
/D5: D32.1 (K), IC1.19 ((OC1A)PD5), R7.1, W28.1
/D6: D33.1 (K), IC1.20 ((ICP)PD6), R8.1, W31.1
/D7: D34.1 (K), IC1.21 ((OC2)PD7), R9.1, W32.1
/MISO: CON2.9, D25.1 (K), IC1.7 ((MISO)PB6), R24.1, W26.1
/MOSI: CON2.1, D24.1 (K), IC1.6 ((MOSI)PB5), R23.1, W22.1
/RST: CON2.5, IC1.9 (~RESET), SW1.2
/RX: D27.1 (K), D36.1 (K), IC1.14 ((RXD)PD0), P7.2, R2.1, W8.1
/SCK: CON2.7, D26.1 (K), IC1.8 ((SCK)PB7), R25.1, W29.1
/TX: D28.1 (K), D37.1 (K), IC1.15 ((TXD)PD1), P7.1, R3.1, W12.1
GND: C2.2, C3.2, C7.1, C8.1, C9.2, CON1.2, CON1.3, CON2.4, CON2.6, CON2.8, CON2.10, D3.2 (A), D4.2 (A), D5.2 (A), D6.2 (A), D7.2 (A), D8.2 (A), D9.2 (A), D10.2 (A), D11.2 (A), D12.2 (A), D13.2 (A), D14.2 (A), D15.2 (A), D16.2 (A), D17.2 (A), D18.2 (A), D19.2 (A), D20.2 (A), D21.2 (A), D22.2 (A), D23.2 (A), D24.2 (A), D25.2 (A), D26.2 (A), D27.2 (A), D28.2 (A), D29.2 (A), D30.2 (A), D31.2 (A), D32.2 (A), D33.2 (A), D34.2 (A), IC1.11 (GND), IC1.31 (AGND), P1.3, P1.4, P2.7, P2.8, P3.9, P7.3, P9.4, P12.4, R1.2, SW1.1, U1.2 (GND)
unnamed: C7.2, IC1.12 (XTAL2), Y1.1
unnamed: C8.2, IC1.13 (XTAL1), Y1.2
unnamed: CON1.1, F1.1
unnamed: D2.1 (K), R1.1
unnamed: D36.2 (A), R35.1
unnamed: D37.2 (A), R36.1
unnamed: P5.8, P10.1, P14.1, R26.2, W63.1
unnamed: P5.7, P10.2, P14.2, R33.2, W59.1
unnamed: P5.6, P10.3, P14.3, R32.2, W55.1
unnamed: P5.5, P10.4, P14.4, R31.2, W51.1
unnamed: P5.4, P10.5, P14.5, R30.2, W47.1
unnamed: P5.3, P10.6, P14.6, R29.2, W43.1
unnamed: P5.2, P10.7, P14.7, R28.2, W39.1
unnamed: P5.1, P10.8, P14.8, R27.2, W35.1
unnamed: P6.8, P11.1, P15.1, R9.2, W64.1
unnamed: P6.7, P11.2, P15.2, R8.2, W60.1
unnamed: P6.6, P11.3, P15.3, R7.2, W56.1
unnamed: P6.5, P11.4, P15.4, R6.2, W52.1
unnamed: P6.4, P11.5, P15.5, R5.2, W48.1
unnamed: P6.3, P11.6, P15.6, R4.2, W44.1
unnamed: P6.2, P11.7, P15.7, R3.2, W40.1
unnamed: P6.1, P11.8, P15.8, R2.2, W36.1
unnamed: P3.8, P9.5, P12.5, R10.2, W33.1
unnamed: P3.7, P9.6, P12.6, R11.2, W37.1
unnamed: P3.6, P9.7, P12.7, R12.2, W41.1
unnamed: P3.5, P9.8, P12.8, R13.2, W45.1
unnamed: P3.4, P9.9, P12.9, R14.2, W49.1
unnamed: P3.3, P9.10, P12.10, R15.2, W53.1
unnamed: P3.2, P9.11, P12.11, R16.2, W57.1
unnamed: P3.1, P9.12, P12.12, R17.2, W61.1
unnamed: P4.8, P8.1, P13.1, R25.2, W62.1
unnamed: P4.7, P8.2, P13.2, R24.2, W58.1
unnamed: P4.6, P8.3, P13.3, R23.2, W54.1
unnamed: P4.5, P8.4, P13.4, R22.2, W50.1
unnamed: P4.4, P8.5, P13.5, R21.2, W46.1
unnamed: P4.3, P8.6, P13.6, R20.2, W42.1
unnamed: P4.2, P8.7, P13.7, R19.2, W38.1
unnamed: P4.1, P8.8, P13.8, R18.2, W34.1

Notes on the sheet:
Power Stage
ICSP- Header
Power Breakout

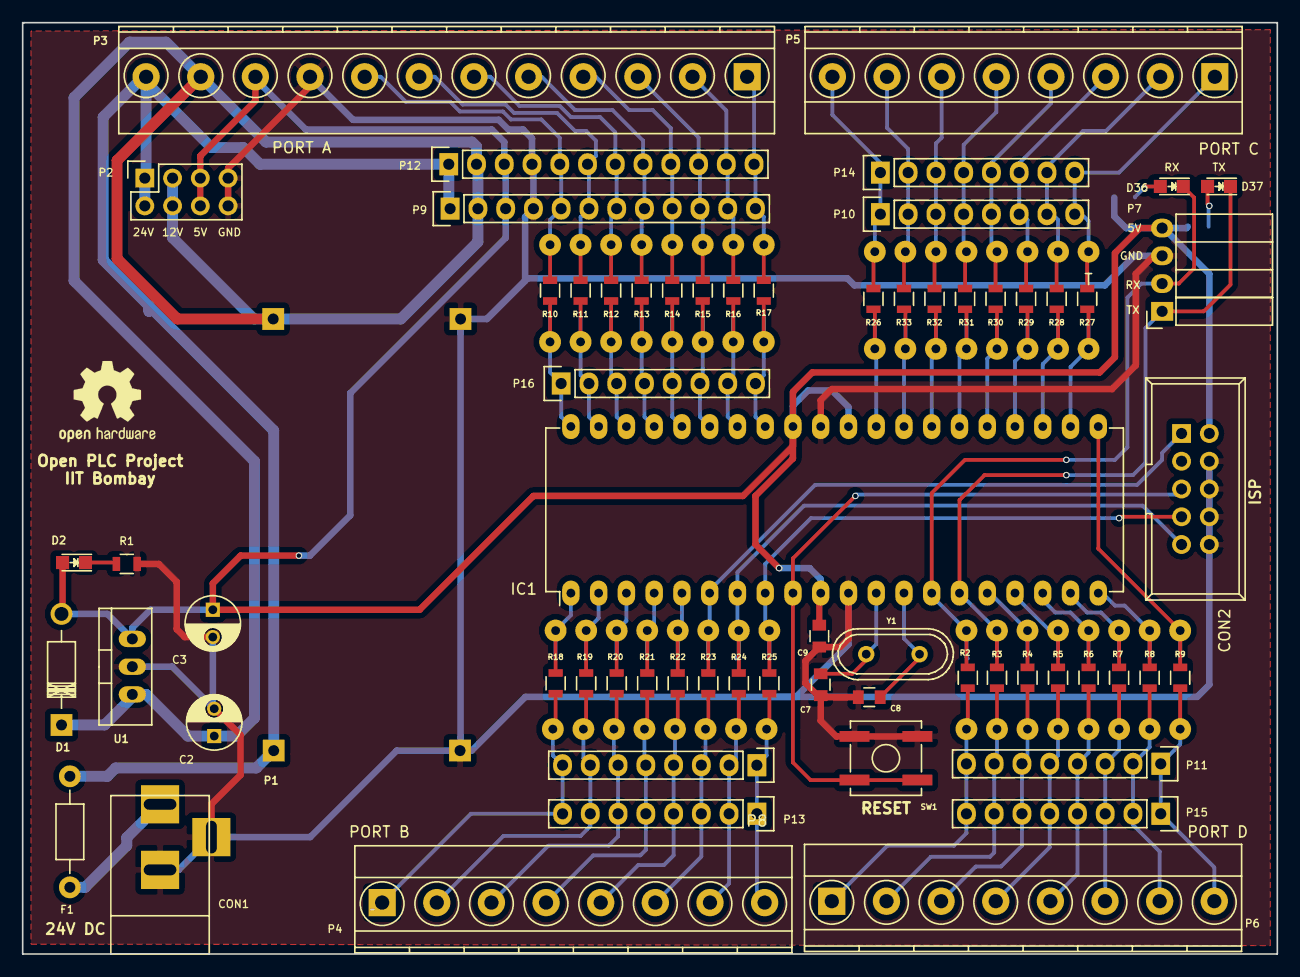
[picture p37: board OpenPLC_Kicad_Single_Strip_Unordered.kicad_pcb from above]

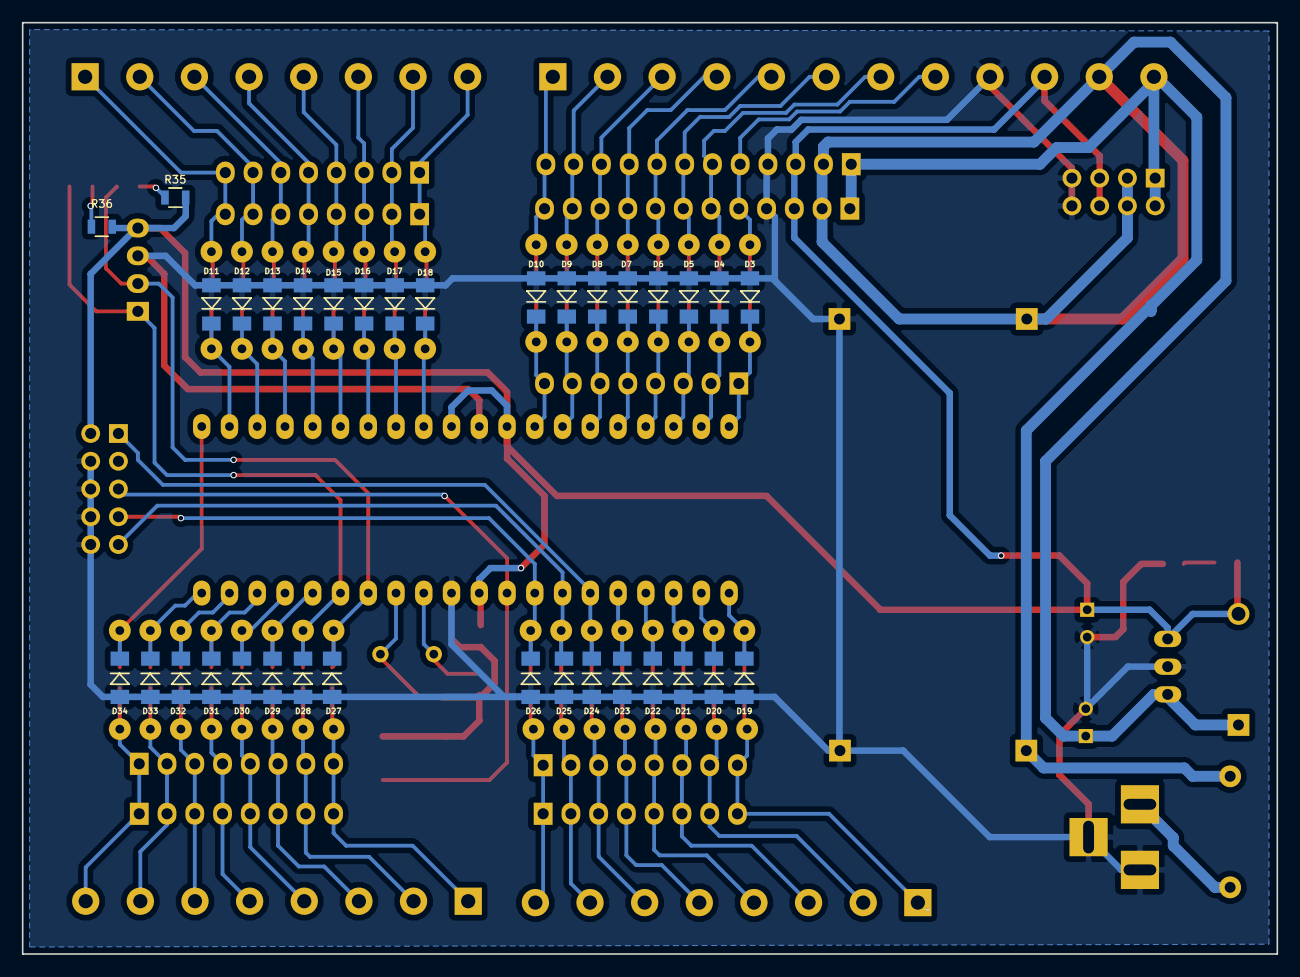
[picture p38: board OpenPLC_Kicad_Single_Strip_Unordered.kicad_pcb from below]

Board: 2 copper layers, 114.8 x 85.2 mm, 163 parts (34 on the bottom side), 75 nets.

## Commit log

2016-04-19 added new file for motor
2016-04-19 added new file for LED
2016-04-19 added chapter for motor
2016-04-22 added fuse settings images
2016-04-26 Removed unnecessary files
    [OpenPLC.sch]
2017-04-01 KiCAD Files
    [OpenPLC_Kicad.sch]
2017-04-03 Open_PLC_Modular KiCAD Files
    [OpenPLC_Kicad_Single_Strip.sch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]
2017-04-04 Folder Hierarchy
    [OpenPLC.sch, OpenPLC_Kicad.sch, OpenPLC_Kicad_Single_Strip.sch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]
2017-04-05 Updated Libraries
    [OpenPLC_Kicad_Single_Strip.sch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]
2017-04-05 Deleted versioning
    [OpenPLC.sch, OpenPLC_Kicad.sch, OpenPLC_Kicad_Single_Strip_Unordered.kicad_pcb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]
2017-04-05 Removed differential pair and improved version compatibility
    [OpenPLC_Kicad_Single_Strip_Unordered.kicad_pcb]
2017-04-05 Added Gerber files
    [OpenPLC_Kicad_Single_Strip_Unordered-B.CrtYd.gbr, OpenPLC_Kicad_Single_Strip_Unordered-B.Cu.gbr, OpenPLC_Kicad_Single_Strip_Unordered-B.Mask.gbr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]
2017-04-25 Moved files from Documentation to Resources folder
    [OpenPLC.sch, OpenPLC_Kicad.sch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]
2018-04-19 Cleaned pu the traces, removed the fuses, made onboard power management
    [OpenPLC_Kicad_Single_Strip_Unordered.kicad_pcb, OpenPLC_Kicad_Single_Strip_Unordered.sch, OpenPLC_V2.kicad_pcb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]
2019-01-28 versioning and finalised V 1.3
    [OpenPLC.sch, OpenPLC_Kicad.sch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]
2019-01-30 directory reorganising
    [OpenPLC.sch, OpenPLC_Kicad.sch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]
2019-02-26 added the entire modules devoloped
    [boardOutline.fcstd, boardoutlineSwithes.fcstd, bomConsolidated.ods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]
2019-03-04 altered switches-board design; shifted resistor
    [switches.kicad_pcb, switches.sch]
2019-03-20 label correction&additions in traffic&switches modules. Updated gerbers - both V1 and modules
    [OpenPLC_V2-B.CrtYd.gbr, OpenPLC_V2-B.Cu.gbr, OpenPLC_V2-B.Mask.gbr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]
2019-03-20 zipped v1.2 gerber and added image
2019-04-09 corrected the gerber file
    [OpenPLC_V2.sch]
2019-05-09 added V2 design files + firmware til now; added .gitignore
    [OpenPLC_V2-B_CrtYd.gbr, OpenPLC_V2-B_Cu.gbr, OpenPLC_V2-B_Mask.gbr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]
2019-07-19 unknown changes!
    [OpenPLC.sch, OpenPLC_Kicad.sch, OpenPLC_Kicad_Single_Strip_Unordered.kicad_pcb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]
2019-08-22 Motor module: grounded 'EN3,4'; terminal connector footprint corrected; 'error led' changed to 3mm; proper footprints for 'switches' and 'towards uC' connectors; proper labelling; added 'designed usi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
    [motor.kicad_pcb, motor.sch]
2020-05-14 [vishnu] Replaced modules and OpenPLCv2 with gitmodules.
    [boardOutline.fcstd, boardoutlineSwithes.fcstd, bomConsolidated.ods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]
2020-05-14 [vishnu] Reorganised and tidied OpenPLCv1 folder
    [OpenPLC_V2-B.CrtYd.gbr, OpenPLC_V2-B.Cu.gbr, OpenPLC_V2-B.Mask.gbr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]
2020-05-19 [vishnu] removed the submodules. Moved v1 hardware design to new directory.
    [OpenPLC.sch, OpenPLC_Kicad.sch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]
2020-09-02 [vishnu] delete the html file in V1.1
    Deleted unwanted bom artifacts from the source-code
2022-05-30 changed directory names
    [OpenPLC.sch, OpenPLC_Kicad.sch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]
2022-05-30 moved module directory
    [boardOutline.fcstd, boardoutlineSwithes.fcstd, bomConsolidated.ods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]
2022-05-31 Added Gerber_Files_OpenPLC_ATmega16.zip
